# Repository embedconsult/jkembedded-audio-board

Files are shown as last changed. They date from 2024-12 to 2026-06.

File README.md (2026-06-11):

# JK-Embedded Audio Board

KiCad design files, firmware plans, and host-side utilities for the JK-Embedded Audio Board and its mikroBUS HAT companion. The design targets multiple SBC hosts (BeaglePlay, BeagleY-AI, TI AM62/68/69 SK-EVM) and uses an MSPM0L1105TRGER as a GPO-extender for configuring the analog muxes.

## Tasks

- [X] A. Requirement analysis (2 days)
- [X] B. Schematic entry (1 weeks after A approval)
- [X] C. Layout (1 weeks after B approval)
- [X] D. Prototype coordination (3 days after C approval)
- [X] E. Test code development (2 weeks after C approval)
- [X] F. Test bench materials (2 weeks after C approval)
- [X] G. Prototype delivery (3 weeks after C approval)
- [ ] H. Sign-off on production design
- [ ] I. First production units ship (12 weeks after H approval)

## Project scope
- **Hardware**: KiCad schematics/PCB for the audio board, mikroBUS HAT, and reference bring-up materials.
- **Firmware**: MSPM0 GPO-extender for mux control (Zephyr preferred; TI SDK acceptable) plus host-side programming utilities and sample integrations for Linux/Zephyr-based hosts.
- **Host integration**: Device-tree overlays and minimal driver/configuration routines for the Si5351 clock generator and the audio codec. Aim to upstream DTS fragments where possible.
- **Production/test utilities**: Board programmers and validation helpers for all target hosts except BeaglePlay (which does not use the mikroBUS HAT).

## Repository layout
- `AGENTS.md` — contribution expectations (scope, CI, documentation rules).
- `docs/` — high-level design notes, firmware/utility plans, and host integration checklists.
- `firmware/` — all firmware and host-side utilities.
  - `mspm0-gpo-extender/` — Zephyr/TI SDK project for the MSPM0L1105TRGER mux controller.
  - `host-programmers/` — Rust/Crystal utilities to program the MSPM0 over I2C/BSL from aarch64 Linux hosts.
  - `host-integration/` — device-tree overlays, clock generator configuration helpers, and sample host code.
- `ci/` — shared CI scripts (e.g., structure checks) used by GitLab and GitHub workflows.
- KiCad sources remain at the repository root for the board and HAT designs.

## Requirements

1. Compatible with RPi HAT connector
2. Texas Instruments TAC5112 for audio codec
3. Texas Instruments DAC53002 for clock generator VCXO control
4. Silicon Laboratories Si5351 clock generator with VCXO (Si5351B)
5. SBC signals:
   * AFSX (WRD) - left/right frame sync (audio board -> SBC)
   * ACLKX (BIT) - bit clock (audio board -> SBC)
   * AXR0 (DI) - data in (SBC -> audio board)
   * AXR1 (DO) - data out (audio board -> SBC)
   * EQEP_A (CNT) - clock counting (audio board -> SBC)
   * CPTSx_HWnTSPUSH or GPIO (TS) - timestamp event (audio board -> SBC)
   * SDA - I<sup>2</sup>C data I/O
   * SCL - I<sup>2</sup>C clock I/O
6. Audio signals:
   * Jacks for stereo in and out at line level (1V<sub>RMS</sub> @ 100Ω) or better
   * Additional I/Os over 3-pin headers
7. Texas Instruments MSPM0L1105TRGER for header signal mapping

## MSPM0 GPO-extender goals
- Mimic a simple I2C GPO-expander interface for host control while optionally auto-selecting mux states per detected host.
- Use BOOTLOADER_SEL and RESET signals to enter the MSPM0 ROM BSL for programming via I2C.
- Keep the binary footprint small and configuration-driven to ease host integration.

## Current validated state
- The local `zephyr` `audio-board` branch includes working MSPM0L110x GPIO support for this board.
- The shared Zephyr board definition for MSPM0 firmware now lives at `firmware/boards/arm/mikrobus_hat/`.
- The BeagleY-AI flash path is working with:
  - `GPIO24` as `MCU_RESET`
  - `GPIO25` as `MCU_BOOTLOADER_SEL`
  - `/dev/hat/mcu_i2c0` as the MSPM0 I2C/BSL bus
  - `bb-imager-cli --verbose flash zepto ... --reset-gpio GPIO24 --bsl-gpio GPIO25 /dev/hat/mcu_i2c0`
- `firmware/blinky/` is the clean minimal Zephyr GPIO validation app and is a better board/GPIO smoke test than the earlier ad hoc debug images.
- The MSPM0 now emulates a `pca9538`-compatible GPIO expander at `0x20`, and Linux can bind the standard `gpio-pca953x` driver to it.
- Zephyr GPIO control has been verified electrically on:
  - `PA19` / `PA20` at `J6`
  - `PA9` / `PA10` through the muxes using an `AN -> INT` short on the mikroBUS socket

## Fresh System Reproduction

Use this path when starting from a fresh BeagleY-AI system with:

- the mikroBUS HAT installed
- the audio board installed on the mikroBUS socket
- no validation jumpers fitted
- no MSPM0 GPIO overlay applied
- no audio overlay applied
- no 1-wire EEPROM programming assumptions

This is the current reproducible starting point for bring-up.

### What to read first

- [bringup.md](/home/beagle/jkembedded-audio-board/bringup.md)
- [firmware/mspm0-gpo-extender/README.md](/home/beagle/jkembedded-audio-board/firmware/mspm0-gpo-extender/README.md)
- [firmware/host-programmers/README.md](/home/beagle/jkembedded-audio-board/firmware/host-programmers/README.md)

### Minimum prerequisites

- `/dev/hat/mcu_i2c0` exists and resolves to the HAT-facing I2C bus
- GPIO line names `GPIO24` and `GPIO25` exist on the host
- `bb-imager-cli` is available from the checked-out `bb-imager-rs` repo
- Zephyr is checked out on the `audio-board` branch and reachable through this repo's `west.yml`

### Reproduction steps

1. Build the MSPM0 firmware in `firmware/mspm0-gpo-extender/app`.
2. Flash it with `bb-imager-cli --verbose flash zepto ... --reset-gpio GPIO24 --bsl-gpio GPIO25 /dev/hat/mcu_i2c0`.
3. Verify the raw I2C bus before doing anything with overlays:
   - the audio board devices should still be present at `0x47`, `0x50`, and `0x60`
   - the MSPM0 application should respond at `0x20`
   - `0x48` should not still be present after returning to normal boot

### Notes

- Keep the initial reproduction point overlay-free. Bind the Linux `pca9538` client or apply the BeagleY-AI overlay only after the raw flash and raw-I2C checks pass.
- If `0x20` shows up as `UU`, a previous `pca953x` binding is still active and should be removed before treating the scan as a clean baseline.
- If `0x48` remains present after flashing, the MSPM0 is still in ROM BSL and `GPIO25` / boot-state handling needs to be checked before moving on.

## Host programmer expectations
- Produce statically linked aarch64 binaries (Rust or Crystal) with no runtime dependencies beyond the Linux kernel.
- Discover GPIO line names and I2C controller symlinks when available; otherwise fall back to board-specific static mappings or CLI arguments.
- Include board profiles for BeagleY-AI, TI AM62 SK-EVM, TI AM68 SK-EVM, and TI AM69 SK-EVM; BeaglePlay is excluded from programming because it does not use the mikroBUS HAT.

## CI overview
- **GitLab CI**: Generates PDFs, BOMs, fabrication outputs, renders, and packaging assets from the KiCad sources, plus layout sanity checks. See `.gitlab-ci.yml`.
- **GitHub Actions**: Mirrors the layout checks and KiCad artifact generation for GitHub users. See `.github/workflows/ci.yml`.
- Shared CI logic lives in `ci/check-project-structure.sh`. Update both pipelines when adding new build steps.

## HAT signal mapping

Where do the various SBC signals need to go to the board connector for each board?

| SBC signal | BP-AM62 | BYAI-AM67A | SK-AM62 | SK-AM68/9 |
| --- | --- | --- | --- | --- |
| WRD | RST (D20)  | 35 (C26) | J7 | 35 |
| BIT | PWM (B20)  | 12 (D25) | 11 (B20)  | 12 |
| DI | AN (E18) | 38 (F23) | 33 (E18)  | 38 |
| DO | INT (B18)  | 40 (B25) | 36 (B18)  | 40 |
| CNT | CIPO (B19) | 36 (A25) | 38 (B19)  | 11 |
| TS | COPI (A19) | 19 (B12) | 19 (B13)  | 19 |
| SDA | SDA (B15)  | 3 (E11) | 3 (K24) | 3 |
| SCL | SCL (A15)  | 5 (B13) | 5 (K22) | 5 |
| 3.3V | +3.3V | 1,17 | 1,17 | 1,17 |
| 5.0V | +5V | 2,4 | 2,4 | 2,4 |
| GND | GND | GND | GND | GND |
| RX | RX (C15) | 10 (C27) | 10 (C15)  | 10 |
| TX | TX (E15) | 8 (F24) | 8 (E15) | 8 |
| SCK | SCK (A20)  | 23 (A9) | 23 (A14)  | 23 |
| SDQ | CS (E19) | 24 (C12) | 24 (A13)  | 24 |

The host overlays use Raspberry Pi / BeagleY-AI-style GPIO line names for the
HAT pins so that host tools can use one line-name vocabulary across boards.
The mikroBUS mux can route some signals to more than one HAT pin; each alternate
route gets its own row and uses the `_A`, `_B`, or `_C` suffix from the HAT
schematic signal names.

| HAT signal | HAT pin | Overlay line name | BeagleY-AI SoC / GPIO | SK-AM62 SoC / GPIO | SK-AM68 SoC / GPIO | SK-AM69 SoC / GPIO |
| --- | --- | --- | --- | --- | --- | --- |
| RST_WRD_A  | 7 | `GPIO4` | W26 / GPIO0_38 | J7 | G25 / WKUP_GPIO0_66 | N34 / WKUP_GPIO0_66 |
| RST_WRD_B  | 35 | `GPIO19` | C26 / GPIO1_12 | D20 / GPIO1_13 | V28 / GPIO0_47 | AD33 / GPIO0_47 |
| PWM_BIT_A  | 11 | `GPIO17` | A26 / GPIO1_8 | B20 / GPIO1_11 | U24 / GPIO0_42 | AF34 / GPIO0_42 |
| PWM_BIT_B  | 12 | `GPIO18` | D25 / GPIO1_11 | G20 / GPIO1_14 | AA24 / GPIO0_46 | AC34 / GPIO0_46 |
| AN_DI_A | 33 | `GPIO13` | E19 / GPIO1_18 | B20 / GPIO1_10 | AE27 / GPIO0_51 | AM37 / GPIO0_51 |
| AN_DI_B | 38 | `GPIO20` | F23 / GPIO1_10 | B19 / GPIO1_8 | T28 / GPIO0_48 | AD38 / GPIO0_48 |
| INT_DO_A | 36 | `GPIO16` | A25 / GPIO1_7 | B18 / GPIO1_9 | T23 / GPIO0_41 | AJ36 / GPIO0_41 |
| INT_DO_B | 40 | `GPIO21` | B25 / GPIO1_9 | C19 / GPIO1_7 | U25 / GPIO0_45 | AL34 / GPIO0_45 |
| CIPO_CNT_A | 38 | `GPIO20` | F23 / GPIO1_10 | B19 / GPIO1_8 | T28 / GPIO0_48 | AD38 / GPIO0_48 |
| CIPO_CNT_B | 36 | `GPIO16` | A25 / GPIO1_7 | B18 / GPIO1_9 | T23 / GPIO0_41 | AJ36 / GPIO0_41 |
| CIPO_CNT_C | 11 | `GPIO17` | A26 / GPIO1_8 | B20 / GPIO1_11 | U24 / GPIO0_42 | AF34 / GPIO0_42 |
| COPI_TS | 19 | `GPIO10` | B12 / MCU_GPIO0_3 | B13 / GPIO1_18 | E24 / WKUP_GPIO0_1 | J34 / WKUP_GPIO0_1 |
| SDA | 3 | `GPIO2` | E11 / MCU_GPIO0_18 | K24 / GPIO0_44 | AF28 / GPIO0_4 | G34 / WKUP_GPIO0_87 |
| SCL | 5 | `GPIO3` | B13 / MCU_GPIO0_17 | K22 / GPIO0_43 | AD25 / GPIO0_5 | M35 / WKUP_GPIO0_65 |
| RX | 10 | `GPIO15` | C27 / GPIO1_13 | C15 / UART5_RXD | AC24 / GPIO0_2 | AJ33 / GPIO0_2 |
| TX | 8 | `GPIO14` | F24 / GPIO1_14 | E15 / UART5_TXD | W25 / GPIO0_1 | AG36 / GPIO0_1 |
| SCK | 23 | `GPIO11` | A9 / MCU_GPIO0_2 | A14 / GPIO1_17 | D26 / WKUP_GPIO0_0 | H38 / WKUP_GPIO0_0 |
| CS_SDQ | 24 | `GPIO8` | C12 / MCU_GPIO0_0 | A13 / GPIO1_15 | C27 / WKUP_GPIO0_3 | J36 / WKUP_GPIO0_3 |
| MCU_RESET  | 18 | `GPIO24` | C8 / MCU_GPIO0_10 | K25 / GPIO0_39 | AD24 / GPIO0_13 | AJ34 / GPIO0_13 |
| MCU_BOOTLOADER_SEL | 22 | `GPIO25` | P21 / GPIO0_42 | A13 / GPIO0_14 | J27 / WKUP_GPIO0_67 | M34 / WKUP_GPIO0_67 |

## GPIO switches

The MSPM0 firmware exposes these selector lines through the emulated
`pca9538` GPIO expander:

| PCA9538 bit | Selector line | MSPM0 pin | SBC signal | HAT pin routes |
| --- | --- | --- | --- | --- |
| 0 | `RST_SEL` | `PA3` | `WRD` | `35` or `7` / `J7` |
| 1 | `PWM_SEL` | `PA4` | `BIT` | `11` or `12` |
| 2 | `AN_SEL` | `PA9` | `DI` | `33` or `38` |
| 3 | `INT_SEL` | `PA10` | `DO` | `36` or `40` |
| 4 | `CIPO_SEL_0`  | `PA11` | `CNT` | `38`, `36` or `11` |
| 5 | `CIPO_SEL_1`  | `PA15` | `CNT` | `38`, `36` or `11` |

Single-bit selector settings:

| Selector line | `0` | `1` |
| --- | --- | --- |
| `RST_SEL` | `WRD` on HAT pin `7` (`GPIO4`) / `J7` | `WRD` on HAT pin `35` (`GPIO19`) |
| `PWM_SEL` | `BIT` on HAT pin `11` (`GPIO17`) | `BIT` on HAT pin `12` (`GPIO18`) |
| `AN_SEL` | `DI` on HAT pin `33` (`GPIO13`)  | `DI` on HAT pin `38` (`GPIO20`)  |
| `INT_SEL` | `DO` on HAT pin `36` (`GPIO16`)  | `DO` on HAT pin `40` (`GPIO21`)  |

Two-bit `CNT` / `CIPO` selector settings:

| `CIPO_SEL_0` | `CIPO_SEL_1` | `CNT` on |
| --- | --- | --- |
| `0` | `0` | not connected |
| `0` | `1` | HAT pin `38` (`GPIO20`) |
| `1` | `0` | HAT pin `36` (`GPIO16`) |
| `1` | `1` | HAT pin `11` (`GPIO17`) |

Selector settings for each target host:

| Target host  | `RST_SEL` | `PWM_SEL` | `AN_SEL` | `INT_SEL` | `CIPO_SEL_0` | `CIPO_SEL_1` |
| --- | --- | --- | --- | --- | --- | --- |
| `BYAI-AM67A` | `1` | `1` | `1` | `1` | `1` | `0` |
| `SK-AM62` | `0` | `0` | `0` | `0` | `0` | `1` |
| `SK-AM68/9`  | `1` | `1` | `1` | `1` | `1` | `1` |

Use `firmware/host-integration/linux/set-mux-profile.sh --host <profile>` to
apply these selector settings from Linux once the MSPM0 `pca9538` target is
reachable. Supported profile names include `byai-am67a`, `sk-am62`, `sk-am68`,
and `sk-am69`; see `firmware/host-integration/README.md` for options and
examples. The base HAT overlays under `firmware/host-integration/linux/<host>/`
provide line names and input pinmux defaults without applying any add-on-board
selector profile.

## Next steps
- Decide whether to keep the measured selector polarity as-is in production firmware or to invert any lines in software before exposing host profiles.
- Decide the production MSPM0 firmware interface:
  - fixed per-host mux profiles, or
  - an I2C target / GPO-expander compatible interface.
- Keep `firmware/blinky/` as the basic board/GPIO validation sample.
- Add device-tree overlays and minimal driver hooks in `firmware/host-integration/` for clock generator initialization and codec wiring.
- Integrate firmware and utility builds into both CI systems.

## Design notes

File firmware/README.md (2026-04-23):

# Firmware and Utilities

This directory contains all firmware and host-side utilities for the JK-Embedded Audio Board and mikroBUS HAT.

## Contents
- `boards/`: Shared Zephyr board definitions for MSPM0 firmware apps. `boards/arm/mikrobus_hat/` is the single source of truth for the MSPM0L1105 HAT controller board.
- `blinky/`: Minimal Zephyr GPIO validation app used to prove board support and flashing on the MSPM0L1105.
- `mspm0-gpo-extender/`: Firmware for the MSPM0L1105TRGER mux controller. Zephyr is preferred; TI SDK is acceptable if Zephyr is blocked.
- `host-programmers/`: Rust/Crystal programmer utilities for aarch64 Linux hosts to load the mux-control firmware over I2C using the MSPM0 ROM BSL.
- `host-integration/`: Device-tree overlays, configuration helpers, and example host code (Linux/Zephyr) for the clock generator and audio codec.

## Guidelines
- Keep host utilities self-contained with static linking; avoid Python or PyPI dependencies.
- Update CI workflows when adding build targets or tests for these components.
- Document board-specific GPIO and I2C mappings alongside the corresponding code.

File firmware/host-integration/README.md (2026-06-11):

# Host Integration Assets

Device-tree overlays, configuration helpers, and example code for integrating the audio board and mikroBUS HAT with supported hosts.

## Focus areas
- Si5351 clock generator setup with DAC53002 VCXO control.
- Audio codec wiring and driver bindings using mainline-compatible DTS fragments.
- Mux control defaults coordinated with the MSPM0 GPO-extender firmware.

## Deliverables
- DTS overlays per supported host (BeagleY-AI, TI AM62/68/69 SK-EVM).
- Minimal configuration utilities or scripts to apply overlays and initialize clocks.
- Notes on upstreaming overlays/driver tweaks to mainline Linux/Zephyr.

## Current MSPM0 host integration

The MSPM0 now emulates a `pca9538`-compatible GPIO expander at `0x20` on the
host-visible I2C bus `/dev/hat/mcu_i2c0` (`i2c-1` on the current BeagleY-AI
setup).

Do not start here for fresh-system bring-up. The initial reproduction point is
the raw build/flash/raw-I2C flow in `bringup.md`, before any overlay or manual
Linux `pca953x` binding is introduced.

### Host-board overlays

Use the matching `jkembedded-mikrobus-hat.dts` overlay under
`firmware/host-integration/linux/<host>/` to instantiate the Linux
`gpio-pca953x` driver with stable line names and base HAT GPIO line names.

Available overlays:

| Host board | Overlay | I2C target |
| --- | --- | --- |
| BeagleY-AI / AM67A | `linux/beagley-ai/jkembedded-mikrobus-hat.dts` | observed live path `/bus@f0000/bus@4000000/i2c@4900000` |
| TI AM62 SK-EVM | `linux/sk-am62/jkembedded-mikrobus-hat.dts` | `&main_i2c2` |
| TI AM68 SK-EVM | `linux/sk-am68/jkembedded-mikrobus-hat.dts` | `&main_i2c4` |
| TI AM69 SK-EVM | `linux/sk-am69/jkembedded-mikrobus-hat.dts` | `&mcu_i2c0` |

Each overlay exposes these selector lines:

- `RST_SEL`
- `PWM_SEL`
- `AN_SEL`
- `INT_SEL`
- `CIPO_SEL_0`
- `CIPO_SEL_1`

These base HAT overlays name the MSPM0 selector lines and host-side HAT GPIO
lines, but they do not drive selector GPIOs to any target profile. Apply a
separate mikroBUS add-on-board overlay, or use the helper below, when a board
needs specific mux settings. The BeagleY-AI overlay keeps the existing live
`i2c-1` `target-path` because that path was validated on hardware. The SK-EVM
overlays use upstream board labels so they follow the base DTS I2C bus layout
used by each target kernel.

### Host mux profile helper

Use `firmware/host-integration/linux/set-mux-profile.sh` after the MSPM0
`pca9538` target is reachable to drive all six selector lines for a supported
host-board profile in one command. The helper uses the overlay-provided line
names when available and otherwise falls back to the detected `pca9538`
`gpiochip` offsets. It binds a temporary Linux `pca9538` client at `0x20`
on `i2c-1` by default when no client exists yet. The base HAT overlays do not
hog the selector GPIOs, so the helper can be used after the overlay loads when
you need to change
profiles interactively.

```console
./firmware/host-integration/linux/set-mux-profile.sh --host byai-am67a
./firmware/host-integration/linux/set-mux-profile.sh --host sk-am62
./firmware/host-integration/linux/set-mux-profile.sh --host sk-am68
./firmware/host-integration/linux/set-mux-profile.sh --host sk-am69
```

Pass `--i2c-bus <bus>` or set `I2C_BUS=<bus>` when the MSPM0 target is on a
different Linux I2C adapter. Use `--dry-run` to print the selected values
without touching GPIOs.

### Validation recipe

Current proven setup:

1. Remove the audio board.
2. Short mikroBUS `AN` to `INT`.
3. Bind the `pca9538` client either by overlay at boot or temporarily with:

```console
echo pca9538 0x20 | sudo tee /sys/bus/i2c/devices/i2c-1/new_device
```

4. Run the scripted validator:

```console
./firmware/host-integration/linux/beagley-ai/validate-mux.sh sample an-int
```

Manual hold-and-probe mode is available too:

```console
./firmware/host-integration/linux/beagley-ai/validate-mux.sh hold an-int low
./firmware/host-integration/linux/beagley-ai/validate-mux.sh hold an-int high
```

The script uses the named selector lines when the overlay is active and falls
back to `gpiochip3` offsets otherwise.

### Remaining selector setups

Use these jumper configurations to finish validating the remaining mux controls:

- `AN -> PWM`

```console
./firmware/host-integration/linux/beagley-ai/validate-mux.sh sample an-pwm
```

Expected output on the current validated board:

```console
AN->PWM low state (expect GPIO18=1 GPIO17=0): 1 0
AN->PWM high state (expect GPIO18=0 GPIO17=1): 0 1
```

- `AN -> MISO`

```console
./firmware/host-integration/linux/beagley-ai/validate-mux.sh sample an-miso
```

Expected output on the current validated board:

```console
AN->MISO state 0 (CIPO_SEL_0=0 CIPO_SEL_1=0) -> GPIO16 GPIO20 GPIO17: 1 1 1
AN->MISO state 1 (CIPO_SEL_0=0 CIPO_SEL_1=1) -> GPIO16 GPIO20 GPIO17: 1 0 1
AN->MISO state 2 (CIPO_SEL_0=1 CIPO_SEL_1=0) -> GPIO16 GPIO20 GPIO17: 0 1 1
AN->MISO state 3 (CIPO_SEL_0=1 CIPO_SEL_1=1) -> GPIO16 GPIO20 GPIO17: 1 1 0
```

- `AN -> RST`

```console
./firmware/host-integration/linux/beagley-ai/validate-mux.sh sample an-rst
```

Probe or read HAT pin `35` (`GPIO19`) and HAT pin `7` (`GPIO4`). HAT pin `7`
is tied to the same signal that is also brought out at `J7` through `R23`
(`0 ohm`), so it is the preferred validation point on this PCB revision.

Expected output:

```console
AN->RST low state (expect GPIO19=1 GPIO4=0): 1 0
AN->RST high state (expect GPIO19=0 GPIO4=1): 0 1
```

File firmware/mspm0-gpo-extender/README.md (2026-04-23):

# MSPM0 GPO-Extender Firmware

The MSPM0L1105TRGER manages mux control for the audio board and mikroBUS HAT.

## Objectives
- Expose mux selection over I2C with a GPO-expander-like register map.
- Provide optional host-detection logic to choose defaults based on SBC profiles.
- Keep the firmware small and configuration-driven; Zephyr preferred, TI SDK acceptable.

## Current state

- The shared Zephyr board `mikrobus_hat` is building and flashing successfully.
- The current reproducible bring-up point is intentionally overlay-free:
  - mikroBUS HAT installed
  - audio board installed
  - no validation jumpers
  - no MSPM0 GPIO overlay applied yet
- Basic GPIO validation is working:
  - `firmware/blinky/` is the clean minimal board support / GPIO smoke test.
  - The `app/` image has been used to verify `PA19` / `PA20` at `J6`.
  - The `app/` image has also been used to verify `PA9` / `PA10` through the muxes with a host-side loopback test.
- PCA9538-style I2C target validation is working:
  - The current `app/` image emulates a `pca9538`-compatible target at `0x20`.
  - Direct `i2ctransfer` register reads/writes succeed.
  - A standard Linux `gpio-pca953x` client can bind at `0x20`.
  - With the `AN -> INT` loopback in place, Linux-driven expander bits 2 and 3 select the expected mux route.
- The BeagleY-AI flash path is now:

```sh
REPO_ROOT="$(git rev-parse --show-toplevel)"
BB_IMAGER_CLI="${BB_IMAGER_CLI:-../bb-imager-rs/target/debug/bb-imager-cli}"
"${BB_IMAGER_CLI}" --verbose flash zepto \
  "${REPO_ROOT}/build/mspm0-zephyr/zephyr/zephyr.hex" \
  --reset-gpio GPIO24 \
  --bsl-gpio GPIO25 \
  /dev/hat/mcu_i2c0
```

- The current `app/` is still a validation app, not the final production mux-control firmware.

## Expected inputs/outputs
- **Inputs**: I2C commands from the host; BOOTLOADER_SEL and RESET to enter MSPM0 BSL.
- **Outputs**: Deterministic mux control lines for each supported host profile.

## Remaining work
- Document and preserve the clean raw-I2C bring-up path before enabling overlays
- Decide how host-profile policy should sit on top of the PCA9538 register model
- Add any host integration needed for line naming or board-specific defaults when binding the Linux `pca953x` client

## Zephyr board configuration

- **Board identifier**: `mikrobus_hat` (see `firmware/boards/arm/mikrobus_hat/`).
- **I2C role**: target/peripheral on `PA0`/`PA1`, currently emulating an 8-bit `pca9538` GPIO expander at `0x20` so existing Linux `pca953x` drivers can toggle the mux selects without changes.
- **I2C pins**: `PA0` = SDA (`HAT_SDA`), `PA1` = SCL (`HAT_SCL`).
- **Bootloader pins**: `PA18` = `MCU_BOOTLOADER_SEL`, `NRST` exposed via the reset net shared with the programming header.
- **Mux GPIO assignments (PCA9538 bit order)**:
  0. `PA3` → `RST_WRD_SEL`
  1. `PA4` → `PWM_BIT_SEL`
  2. `PA9` → `AN_DI_SEL`
  3. `PA10` → `INT_DO_SEL`
  4. `PA11` → `CIPO_CNT_SEL0`
  5. `PA15` → `CIPO_CNT_SEL1`
  6. reserved for future use
  7. reserved for future use

The shared board DTS in `firmware/boards/arm/mikrobus_hat/mikrobus_hat.dts` documents the current pinctrl and validation GPIO map. The current `app/` implementation uses the PCA9538 register model directly rather than the older EEPROM target shim.

## Build and CI smoke test

The Zephyr build smoke test lives in `app/` and targets `mikrobus_hat`. The repo `west.yml` now points Zephyr at the `audio-board` branch and imports only the required modules (`cmsis_6` and `hal_ti`). Run the same script locally from the repo root:

```sh
./ci/build-zephyr-mspm0.sh
```

The script initializes an isolated west workspace under `build/`, uses the Zephyr SDK toolchain if it is installed at `/opt/zephyr-sdk` (as in CI containers), and rebuilds from a clean tree to catch board or configuration regressions. Local bring-up also works with any sibling or external Zephyr checkout on the same branch. You can perform the same steps manually:

```sh
west init -l .
west update --narrow --fetch-opt=--depth=1
west build -p always \
  -b mikrobus_hat \
  "$PWD/firmware/mspm0-gpo-extender/app" \
  --build-dir "$PWD/build/mspm0-zephyr" \
  -- \
  -DBOARD_ROOT="$PWD/firmware"
```

CI also runs `clang-format` (using `.clang-format` from Zephyr) and `dtslint.py` on the board DTS before building.

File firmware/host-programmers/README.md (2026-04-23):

# Host Programmer Utilities

Utilities in this directory program the MSPM0L1105TRGER mux-control firmware from supported hosts.

## Requirements
- Rust or Crystal implementation only; produce statically linked aarch64 Linux binaries.
- No Python or PyPI dependencies.
- Use GPIO line names and I2C controller symlinks when available; allow CLI overrides and static board profiles otherwise.

## Target hosts
- BeagleY-AI
- TI AM62 SK-EVM
- TI AM68 SK-EVM
- TI AM69 SK-EVM

BeaglePlay is excluded because it does not use the mikroBUS HAT.

## Current status
- GPIO line-name based BSL entry is working on the BeagleY-AI host
- `bb-imager-cli flash zepto` is the current working flash path
- The working invocation is:

```console
BB_IMAGER_CLI="${BB_IMAGER_CLI:-../bb-imager-rs/target/debug/bb-imager-cli}"
"${BB_IMAGER_CLI}" --verbose flash zepto \
  /path/to/zephyr.hex \
  --reset-gpio GPIO24 \
  --bsl-gpio GPIO25 \
  /dev/hat/mcu_i2c0
```

- Flash verify may still false-fail on this transport; use `--no-verify` if the
  image is written successfully but the CRC stage reports an error

## Planned features
- Board detection and safe default mux selection
- More robust verification/readback over I2C BSL
- Optional dry-run mode for validation during production testing

## BeagleY-AI (current target) resource mapping

### Image used for testing

```
$ cat /etc/dogtag
BeagleBoard.org Debian Bookworm Xfce Image 2025-11-25
```

### HAT I2C

Preferred path:

`/dev/hat/mcu_i2c0`

Resolved bus on this host:

`/dev/i2c-1`

```
beagle@beagle:~/jkembedded-audio-board$ i2cdetect -y -r 1
     0  1  2  3  4  5  6  7  8  9  a  b  c  d  e  f
00:                         -- -- -- -- -- -- -- -- 
10: -- -- -- -- -- -- -- -- -- -- -- -- -- -- -- -- 
20: -- -- -- -- -- -- -- -- -- -- -- -- -- -- -- -- 
30: -- -- -- -- -- -- -- -- -- -- -- -- -- -- -- -- 
40: -- -- -- -- -- -- -- 47 48 -- -- -- -- -- -- -- 
50: 50 -- -- -- -- -- -- -- -- -- -- -- -- -- -- -- 
60: 60 -- -- -- -- -- -- -- -- -- -- -- -- -- -- -- 
70: -- -- -- -- -- -- -- --                         
```

### HAT GPIO

| Signal | pin | linename |
| --- | --- | --- |
| MCU_RESET | 18  | GPIO24 |
| MCU_BOOTLOADER_SEL | 22  | GPIO25 |

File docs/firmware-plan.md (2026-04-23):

# Firmware and Host Integration Plan

This document outlines the planned firmware, host utilities, and integration steps for the JK-Embedded Audio Board and mikroBUS HAT.

## MSPM0L1105TRGER GPO-extender
- **Goal**: Provide a simple I2C-accessible GPIO expander interface, or a fixed mux-profile image, to select mux configurations for each supported host platform.
- **Preferred stack**: Zephyr. This is no longer blocked: local board support, flashing, and GPIO control are working.
- **Bootloading**: The current working path uses `bb-imager-cli flash zepto` with line names `GPIO24` and `GPIO25` and the host bus `/dev/hat/mcu_i2c0`.
- **Host awareness**: Support optional host detection (GPIO line names or static profiles) to pre-select safe mux defaults.
- **Validated so far**:
  - `PA19` / `PA20` GPIO control at `J6`
  - `AN_SEL` / `INT_SEL` mux control via `AN -> INT` loopback
  - `PWM_SEL` mux control via `AN -> PWM` loopback
  - `CIPO_SEL_0` / `CIPO_SEL_1` mux control via `AN -> MISO` loopback
  - `RST_SEL` polarity using HAT pin `7` (`GPIO4`), which is tied to the `J7` signal through `R23` (`0 ohm`)
  - PCA9538-compatible I2C target emulation at `0x20`
  - Linux `gpio-pca953x` binding against the emulated target

## Host programmer utility
- **Language**: Rust or Crystal only; produce statically linked aarch64 binaries with no dynamic library dependencies.
- **Functionality**:
  - Detect the appropriate I2C controller via `/dev` symlinks when present; otherwise select per-board defaults.
  - Assert BOOTLOADER_SEL/RESET to enter the BSL and program the MSPM0 with the mux-control firmware image.
  - Offer command-line arguments to override board detection, I2C bus number, and GPIO line names.
- **Current working command**:

```sh
BB_IMAGER_CLI="${BB_IMAGER_CLI:-../bb-imager-rs/target/debug/bb-imager-cli}"
"${BB_IMAGER_CLI}" --verbose flash zepto \
  /path/to/zephyr.hex \
  --reset-gpio GPIO24 \
  --bsl-gpio GPIO25 \
  /dev/hat/mcu_i2c0
```
- **Targets**: BeagleY-AI, TI AM62 SK-EVM, TI AM68 SK-EVM, TI AM69 SK-EVM. BeaglePlay is not programmed because it does not use the mikroBUS HAT.

## Linux/Zephyr host integration
- **Clock generator (Si5351)**: Provide device-tree overlays and minimal configuration helpers to initialize VCXO control via DAC53002.
- **Audio codec**: Rely on mainline support for the TI AIC/TAS codec; supply DTS fragments to bind to the correct buses and clocks.
- **Configuration flow**: host binds PCA9538-compatible MSPM0 target -> mux selection via named GPIO lines -> clock generator setup -> codec registration.
- **Upstreaming**: Keep DTS overlays minimal and align node names/compatible strings with mainline conventions to ease upstream submission.

## Directory pointers
- `firmware/mspm0-gpo-extender/`: Firmware sources, build scripts, board configuration overlays, and usage documentation.
- `firmware/host-programmers/`: Programmer utility, board profiles, release binaries, and usage documentation.
- `firmware/host-integration/`: DTS overlays, helper scripts, and documentation for host configuration.
- `docs/`: Additional design notes, bring-up procedures, and any shared usage documentation.

## Next integration steps
1. Update host-side integration and default-profile code to use the measured `RST_SEL` polarity: `0 -> HAT pin 7 / GPIO4 / J7`, `1 -> HAT pin 35 / GPIO19`.
2. Apply the BeagleY-AI host overlay in normal boot flows so Linux exposes the emulated PCA9538 lines as `RST_SEL`, `PWM_SEL`, `CIPO_SEL_0`, `CIPO_SEL_1`, `AN_SEL`, and `INT_SEL` without manual `new_device` binding.
3. Decide the production MSPM0 firmware policy on top of the validated PCA9538 register model: pure host-controlled muxing, fixed power-on defaults, or host-profile-based defaults.

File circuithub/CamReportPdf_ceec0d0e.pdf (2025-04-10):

Single PCB View - Original

Top View | Bottom View

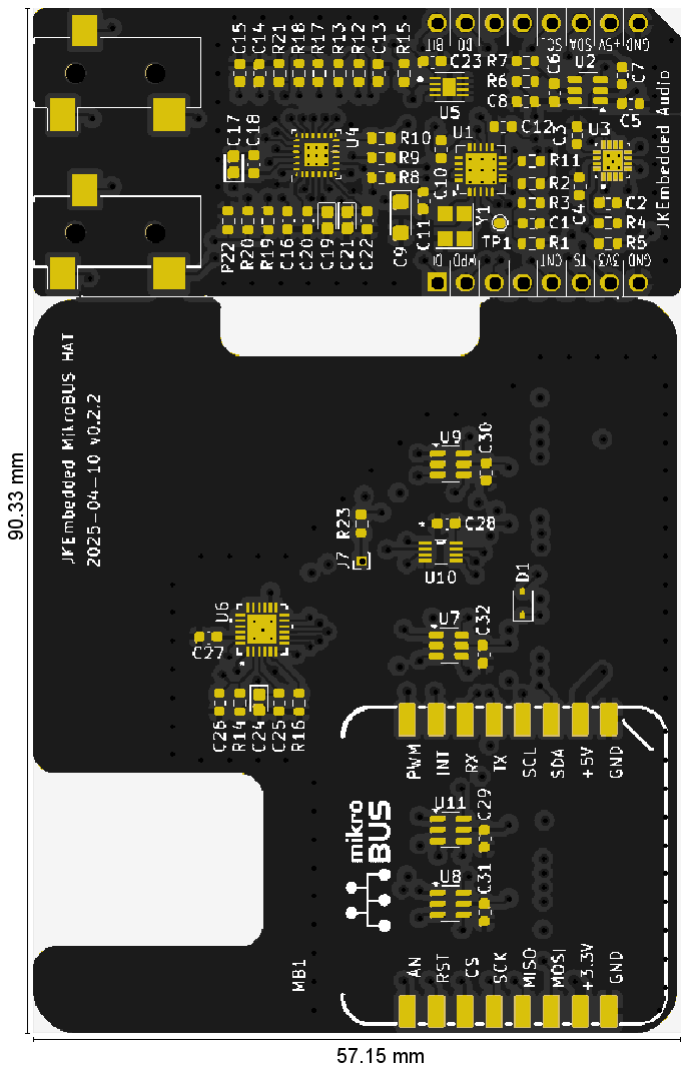
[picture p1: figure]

Summary - General - Original

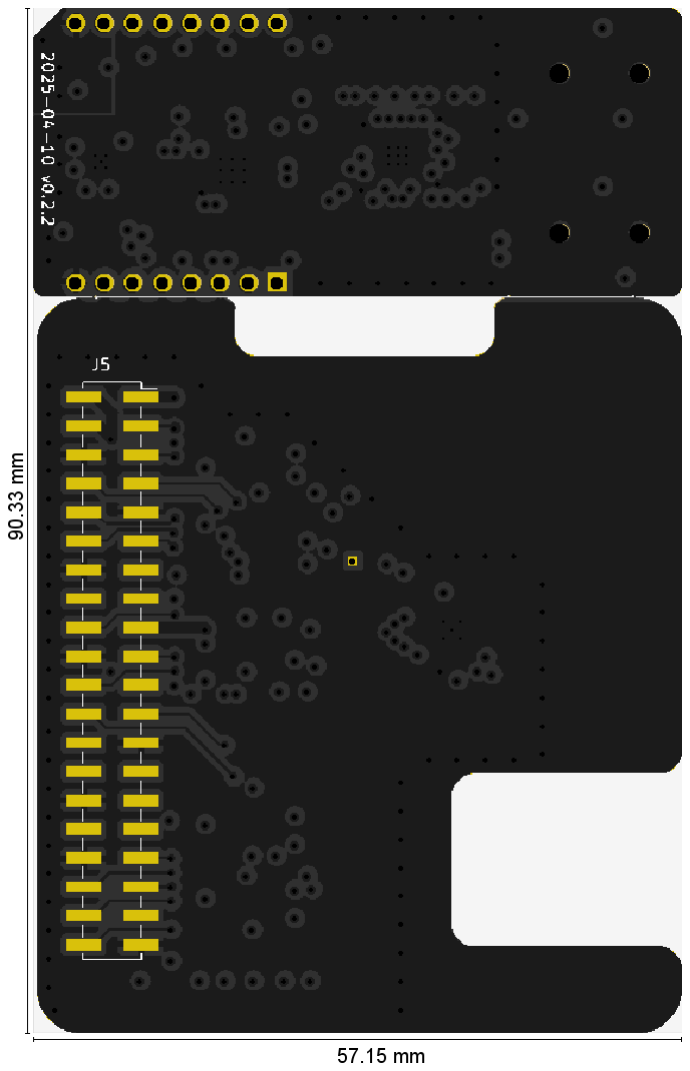
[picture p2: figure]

PCB Size | 57.15 mm x 90.329 mm | Customer Panel Size
PCB Thickness | 1.6 mm | Max. Aspect Ratio on PTH | 6.4
Copper Layers | 4 | Pressing Stages | 1
Surface Finish | unknown | Drill Hole Density | 650 Holes/dm²
Solder Mask | Both | Testable Points | 379
Solder Mask Color | Green | Min. SMD/BGA Size | 0.24 mm
Legend | Both | !HolesInPadPth! | Yes
Legend Color | White | !HolesInPadBlind! | No
Edge Connector Area | 0 dm² | Stacked Vias
Peeloff Mask | No | Castellated | No
Carbon Mask | No | Anomalies | Yes
1 | 2 | 3 | 4 | 5 | 6 | 7 | 8 | 9
10 | 11 | 12 | 13 | 14 | 15 | 16 | 17 | 18

Summary - Copper Layer Minima - Original

Type | Copper Width | Critical Copper Width

Trace Width Critical Trace

| | | | Width | Copper to Copper Clr. | Trace to Trace Clr. | Same Net Clr. | Ring | Copper to Outline Clr.
| mm | mm | mm | mm | mm | mm | mm | mm | mm
Outer | 0.160 | 0.237 | 0.250 | 0.250 | 0.142 | 0.200 | 0.025 | 0.138 | 0.000
Inner | 0.249 | 0.250 | 0.250 | 0.250 | 0.200 | 0.200 | 0.134 | 0.125 | 0.000
Integr8tor v2023.12-240208 | Page1

The information on this document is not only based on files in a clearly defined format, but also on freely structured files and inference rules. CircuitHub strives to make it as accurate as possible, but it cannot guarantee the result in all situations. This information is used at the sole risk of its user.

Name | rev_64925.zip | Id. | 26740 - QED Handled
Report Generated on | Apr 10, 2025, 4:57:55 PM | Customer
Board Id | | Article Id

19 | 20 | 21 | 22 | 23 | | 24
25 | 26 | 27 | 28 | 29 | 30 | 31

Summary - Copper Layer Minima - Original

Type | Copper to Plated Clr. | Copper to NPTH Clr.
!Min.Clr.Overal
l!

!Min.Clr.toPad! !Min.Clr.toTrac e!

!Min.Clr.toRegi
on!

!Min.Clr.Overal
l!

!Min.Clr.toPad! !Min.Clr.toTrac e!

!Min.Clr.toRegi
on!
mm | mm | mm | mm | mm | mm | mm | mm
Outer | 0.400 | 0.400 | 0.400 | 0.676 | 0.128 | >1.600 | >1.600 | 0.128
Inner | 0.332 | 0.400 | 0.332 | 0.676 | 0.128 | >1.600 | 0.275 | 0.128

Summary - Sequences - Original

Type | Sequences | Tools | Min. End
Dia.

Max. End
Dia.
Holes | Routs | Ring on
Outer

Ring on
Inner

Hole to
Copper Clr.
| | | mm | mm | | | mm | mm | mm
PTH | 1 | 4 | 0.250 | 1.000 | 301 | 0 | 0.138 | 0.125 | 0.332
NPTH | 1 | 1 | 1.700 | 1.700 | 4 | 0 | >0.800 | >0.800 | 0.128
Total | 2 | 5 | 0.250 | 1.700 | 305 | 0 | 0.138 | 0.125 | 0.128

Summary - Rout - Original

Type | Tools | Min. End Dia. | Max. End Dia. | Rout Length
| | | | | mm | | mm | | mm
Plated
NPTH

Total

Report Generated on | Apr 10, 2025, 4:57:55 PM | Customer
Board Id | | Article Id

Stackup - Original

Pressing Stages | 1

Files - Original

Initial | Renamed | Function | Position | Color | Thickness
Base | Finished
| | | | | mm | mm
doc-top.pho | drawing_1 | drawing | top
stencil-top.pho | paste-top | paste | top
silkscreen-top.pho | silk-top | silk | top | white | unknown | unknown
solder-mask-top.pho | mask-top | mask | top | black | unknown | unknown
copper-top.pho | top | outer | 1 | | | 0.035 | unknown
copper-inner-1.pho | in2 | inner | 2 | | | 0.035 | unknown
copper-inner-2.pho | in3 | inner | 3 | | | 0.035 | unknown
copper-bottom.pho | bot | outer | 4 | | | 0.035 | unknown
solder-mask-bottom.pho | mask-bot | mask | bottom | black | unknown | unknown
silkscreen-bottom.pho | silk-bot | silk | bottom | white | unknown | unknown
stencil-bottom.pho | paste-bot | paste | bottom
drill-npth.pho | npth | unplated | 1-4
drill.pho | pth | plated | 1-4
doc-bottom.pho | drawing | drawing | bottom
outline.pho | outline | cad_outline | none

PCB (Single) - Original

PCB Size | Outline Type | Outline Length | Outline Area | Copper Layers | PCB Thickness
mm x mm | | mm | dm² | | mm
57.150 x 90.329 | real | 443.948 | 0.4695 | 4 | 1.600

Customer Panel (Delivery Array, Assembly Panel) - Original

Original Image | Panel Size | Left | Right | Top | Bottom | X Spacing | Y Spacing | PCB's | Depanel Rout Length
| mm x mm | mm | mm | mm | mm | mm | mm | | mm
Report Generated on | Apr 10, 2025, 4:57:55 PM | Customer
Board Id | | Article Id

Thickness - Original

No license to generate this information.

Copper Layer Minima & Area - Original

File | Pos. Copper Width | Critical
Copper Width

Trace Width Critical Trace Width

Copper to
Copper Clr.

Same Net
Clr.

Copper Area

mm | mm | mm | mm | mm | mm | dm² | %
top | 1 | 0.237 | 0.237 | 0.250 | 0.250 | 0.142 | 0.025 | 0.3837 | 82
in2 | 2 | 0.250 | 0.250 | 0.250 | 0.250 | 0.200 | 0.207 | 0.3817 | 81
in3 | 3 | 0.249 | 0.250 | 0.250 | 0.250 | 0.200 | 0.134 | 0.3863 | 82
bot | 4 | 0.160 | 0.250 | 0.250 | 0.250 | 0.200 | 0.134 | 0.4074 | 87

Copper Layer Minima - Copper to Drill Minima - Original

File | Pos. | Ring | Copper to Drill Clr. | Copper to Outline Clr.
Overall | Via | Laser Via Comp. | Mech. | Plated | NPTH | Overall | to Pad | to Trace | to Region
mm | mm | mm | mm | mm | mm | mm | mm | mm | mm | mm
top | 1 | 0.138 | 0.138 | 0.175 | 0.400 | 0.128 | 0.000 | 0.371 | >1.600 | 0.000
in2 | 2 | 0.125 | 0.125 | 0.175 | 0.332 | 0.128 | 0.000 | 0.371 | >1.600 | 0.000
in3 | 3 | 0.125 | 0.125 | 0.175 | 0.386 | 0.128 | 0.000 | 0.371 | >1.600 | 0.000
bot | 4 | 0.175 | 0.200 | 0.175 | 0.400 | 0.128 | 0.000 | 0.371 | >1.600 | 0.000

Copper Layers - Copper to Copper Clearances - Original

File | Pos. | Copper to Copper Clr.
Overall | Pad to Pad | Pad to Track | Track to Track | Trace to Trace
mm | mm | mm | mm | mm
top | 1 | 0.142 | 0.142 | 0.200 | 0.200 | 0.200
in2 | 2 | 0.200 | 0.200 | 0.200 | 0.200 | 0.200
in3 | 3 | 0.200 | 0.200 | 0.200 | 0.200 | 0.200
bot | 4 | 0.200 | 0.200 | 0.260 | 0.250 | 0.250

Copper Areas - Original

Side | Total | Free of | Edge Connectors
Solder Mask
(as supplied)

Solder Mask
(open vias)
Gold Mask Silver Mask | Fingers | Finger Size | Total Area

dm²

dm²

dm²

dm²

dm² | mm x mm | dm²
Top (incl. 1/2 plated holes and routs) | 0.4108 | 0.0321 | 0.0616
Bottom (incl. 1/2 plated holes and routs) | 0.4346 | 0.0185 | 0.0482
Total (incl. plated holes and routs) | 0.8453 | 0.0505 | 0.1098 | 0
Plated holes and routs | 0.0633 | 0.0083 | 0.0633
Top (without plated holes and routs) | 0.3791 | 0.0279 | 0.0300
Bottom (without plated holes and routs) | 0.4029 | 0.0143 | 0.0165
Total (without plated holes and routs) | 0.7821 | 0.0422 | 0.0465
Report Generated on | Apr 10, 2025, 4:57:55 PM | Customer
Board Id | | Article Id

Drill Tools - Original

File | Tool
Nr.
Span | Type | Function Method Filled Via | Counter | Dia. | Tol. - | Tol. + Holes
in PCB

Routs
in PCB

Double
Hits

Predrill
Hits
| | | | | | | mm | mm | mm
npth | 10 | 1-4 NPTH | mech. | mech. | unknown unknown | 1.700 0.000 0.000 | 4 | 0 | 0 | 0
pth | 10 | 1-4 PTH | via | mech. | unknown unknown | 0.250 0.000 0.000 | 28 | 0 | 0 | 0
pth | 11 | 1-4 PTH | via | mech. | unknown unknown | 0.400 0.000 0.000 | 256 | 0 | 0 | 0
pth | 12 | 1-4 PTH | comp. | mech. | unknown unknown | 0.500 0.000 0.000 | 1 | 0 | 0 | 0
pth | 13 | 1-4 PTH | comp. | mech. | unknown unknown | 1.000 0.000 0.000 | 16 | 0 | 0 | 0

Drill Tools - Drill vs Copper - Original

File | Tool
| Nr.
Span | Type | Function Method | Dia. Ring on
| | | | | | Outer | Ring on Inner | Min. Pad Size | Via in
Pad

Plated to Copper Clr.
| | | | | | | | | | !Min.Clr .Overall ! | !Min.Clr .toPad! | !Min.Clr .toTrac e! | !Min.Clr .toRegi on!
| | | | | mm | mm | mm | mm | | mm | mm | mm | mm
npth | 10 | 1-4 NPTH | mech. | mech. | 1.700 >0.800 >0.800
pth | 10 | 1-4 PTH | via | mech. | 0.250 | 0.138 | 0.125 | 0.500 | 5 | 0.332 | 0.425 | 0.332 | >0.800
pth | 11 | 1-4 PTH | via | mech. | 0.400 | 0.200 | 0.200 | 0.800 | 0 | 0.400 | 0.400 | 0.400 | 0.700

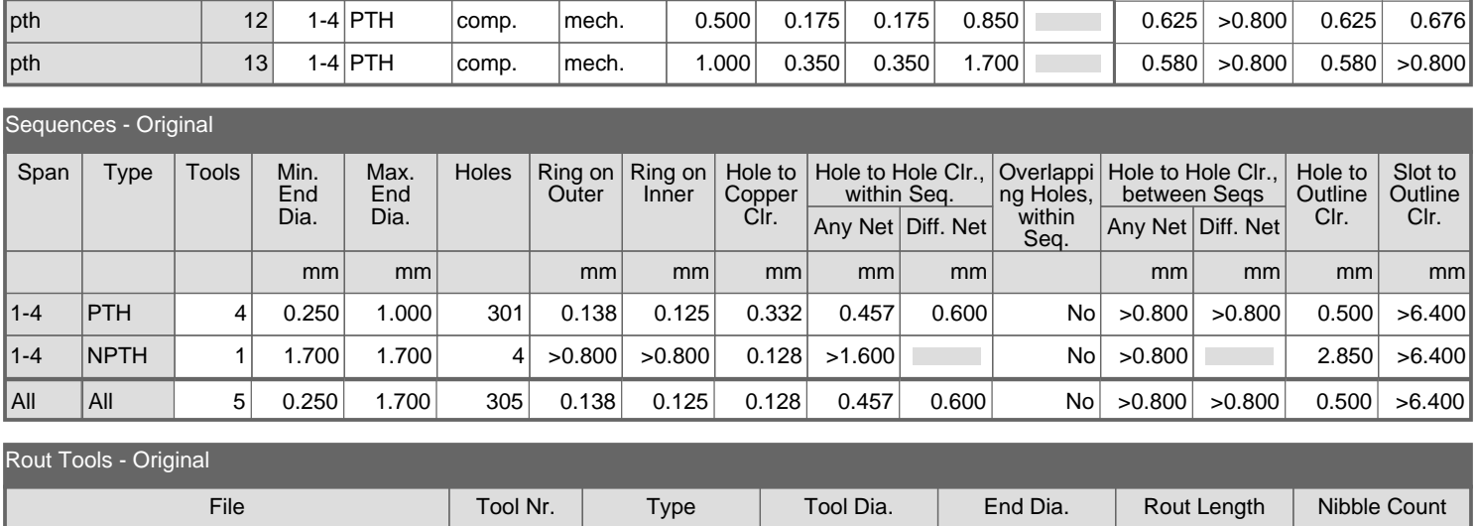
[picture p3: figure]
pth; 1-4 PTH; comp.; mech.; Sequences - Original; Span; Type; Tools; Min.; End Dia.; Max. End Dia.; Holes Ring on Outer; Ring on Inner; Hole to Copper Clr.; Hole to Hole Clr., within Seq.; Overlappi ng Holes, within Seq.; Hole to Hole Clr., between Seqs; Hole to Outline Clr.; Slot to Outline; Clr. Any Net Diff. Net; Any Net Diff. Net; PTH; NPTH; All; Rout Tools - Original; File; Tool Nr.; Tool Dia.; Rout Length; Nibble Count

mm | mm | mm

Routed Holes - Original

File | Hole Nr. | Instances | X Size | Y Size | Rout Length | Nibble Count
mm | mm | mm

Sequences Analysis - Original

File | Pos. Stacked
Vias
| Overlap ped Vias | Via Plug Clr.
Top Tool | Bottom Tool
Top Drill File | Tool Nr. | Dia. | Bottom Drill File Tool Nr. | Dia.
| | mm | | mm | | mm
Report Generated on | Apr 10, 2025, 4:57:56 PM | Customer
Board Id | | Article Id

SMD (Incl. BGA) - Original

SMD (Incl. BGA) | SMD (Excl.
BGA)

BGA

Side | Pads | Min. Pad Pitch of Min.
Pad

Solder
Mask
Defined
Pads
Pads | Pads | Min. Pad | Min. Pitch | All Tracks Centered

Drilled Pads

mm | mm | mm | mm
Top | 277 | 0.240 | 0.500 | 0 | 277 | 0

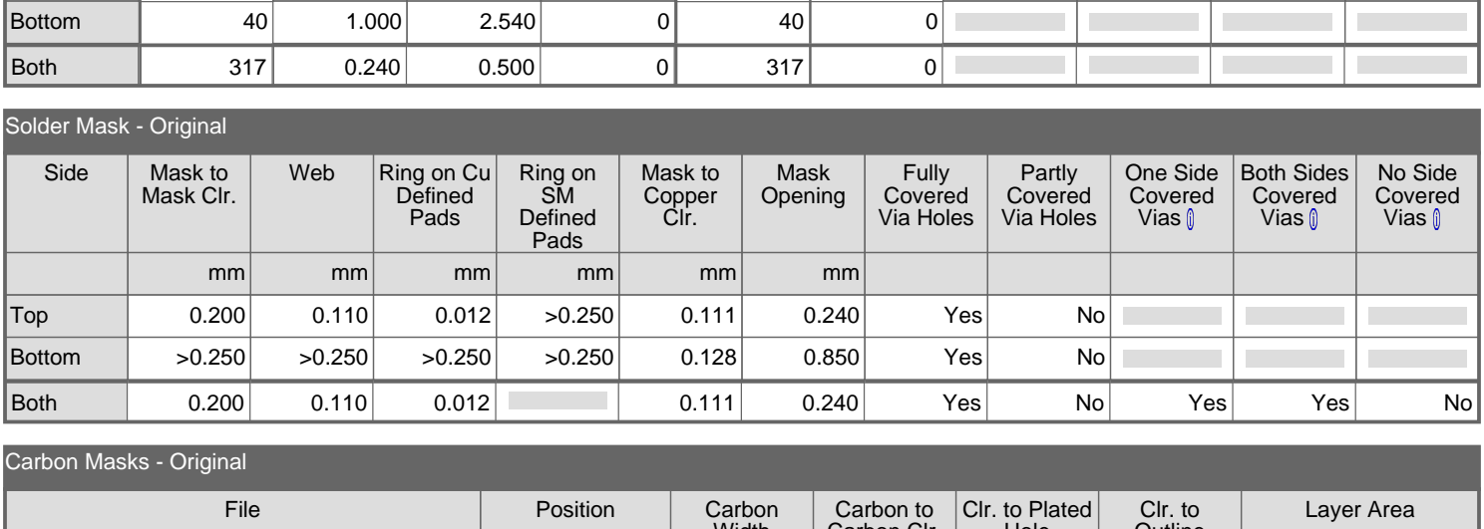
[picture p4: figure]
Bottom; Both; Solder Mask - Original; Side; Mask to; Mask Clr.; Web; Ring on Cu; Defined Pads; Ring on SM Defined Pads; Mask to Copper Clr.; Mask Opening; Fully Covered Via Holes; Partly Covered Via Holes; One Side Covered Vias; Both Sides Covered Vias; No Side Covered Vias; Top; Yes; Carbon Masks - Original; File; Position; Carbon; Carbon to; Clr. to Plated; Clr. to; Layer Area

Width

Carbon Clr.

Hole

Outline
mm | mm | mm | mm | dm² | %

Peeloff Masks - Original

File | Position | Min.
Peelable
Width

Peelable to
Peelable Clr.

Clr. to Plated
Hole

Clr. to
Outline

Layer Area

mm | mm | mm | mm | dm² | %

Legend Layers - Original

File | Position | Legend Width | Legend to
Legend Clr.

Legend to
(Comp/SMD/BGA)
Pad Clr.

Layer Area

| | mm | mm | mm | dm² | %
silk-top | top | 0.100 | 0.043 | 0.140 | 0.0178 | 4
silk-bot | bottom | 0.120 | 0.187 | 0.200 | 0.0012 | 0

Gold Layers - Original

File | Position | Gold to Gold Clr. | Clr. to Outline | Layer Area
| | | mm | mm | dm² | %

Heatsink Layers - Original

File | Position | Heatsink to
| | Heatsink Clr.
Clr. to Outline | Layer Area
| | | mm | mm | dm² | %
Board Id | Article Id

Scoring - Minimum Clearance - Original

No license to generate this information.

Bare Board Test - Original

Side | Testable Points (TPs)
Max. TP Density | SMD Pads | Min. SMD Pad | Pitch of Min.
SMD Pad

Edge Connector
Fingers

Number of Nets

| | TP/dm² | | | mm | | mm
Top | 322 | 2701 | | 277 | 0.240 | | 0.500 | | 0
Bottom | 57 | 679 | | 40 | 1.000 | | 2.540 | | 0
Both | 379 | 2701 | | 317 | 0.240 | | 0.500 | | 0 | | 110

DFM Classes - Original

Standard | Advanced
| | | 1 | 2 | 3 | 4 | 5 | 6 | 7 | 8 | 9
Track & Gap | Min Clearance (Track-Track / Track-Pad / Pad-Pad) | 0.142 | 0.300 | 0.250 | 0.200 | 0.150 | 0.130 | 0.120 | 0.100 | 0.075 | 0.060
| Min Track Width / Thermal Gap | 0.237 | 0.300 | 0.250 | 0.200 | 0.150 | 0.130 | 0.120 | 0.100 | 0.075 | 0.060

Ring for IPC Class

2 | Outer Min Layer Annular Ring | 0.138 | 0.250 | 0.220 | 0.200 | 0.150 | 0.130 | 0.120 | 0.100 | 0.075 | 0.060
| Inner Min Layer Annular Ring | 0.125 | 0.250 | 0.220 | 0.200 | 0.150 | 0.130 | 0.120 | 0.100 | 0.075 | 0.060
Aspect Ratio | Max Aspect Ratio for Plated Hole
6.400 | 8.000 | 8.000 | 8.000 | 8.000 10.000 10.000 10.000 10.000 10.000
Drill - Cu | Distance PTH to PTH | 0.457 | 0.600 | 0.500 | 0.400 | 0.350 | 0.300 | 0.300 | 0.275 | 0.250 | 0.230
| Distance NPTH to Cu on inner layers | 0.128 | 0.250 | 0.250 | 0.200 | 0.200 | 0.150 | 0.150 | 0.150 | 0.100 | 0.100
| Distance NPTH to Cu on outer layers | 0.128 | 0.250 | 0.250 | 0.200 | 0.200 | 0.150 | 0.150 | 0.150 | 0.100 | 0.100
Cu Thickness | Max Cu Thickness that can be etched | | 0.175 | 0.140 | 0.105 | 0.070 | 0.070 | 0.035 | 0.035 | 0.035 | 0.017
Solder Mask | Solder Mask Annular Ring | 0.012 | 0.100 | 0.075 | 0.050 | 0.050 | 0.050 | 0.050 | 0.040 | 0.030 | 0.010
| Solder Mask SolderWeb | 0.110 | 0.150 | 0.125 | 0.100 | 0.100 | 0.100 | 0.100 | 0.080 | 0.075 | 0.075

Anomalies - Original

Outline cutout slightly clips functional copper in layer 'top' Outline cutout slightly clips functional copper in layer 'in2'
Outline cutout slightly clips functional copper in layer 'in3'
Outline cutout slightly clips functional copper in layer 'bot'
[AutoClean] Functional copper outside or touching outline in layer 'top' [AutoClean] Functional copper outside or touching outline in layer 'in2' [AutoClean] Functional copper outside or touching outline in layer 'in3' [AutoClean] Functional copper outside or touching outline in layer 'bot' Functional copper outside or touching outline in layer 'top'
Functional copper outside or touching outline in layer 'in2'
Functional copper outside or touching outline in layer 'in3'
Functional copper outside or touching outline in layer 'bot'
Board Id | Article Id

Input Remarks - Original

Gerber import: Invalid coincident draw, continuing without cleanup 'copper-bottom.pho'
Gerber import: Self-intersecting contours are detected, continuing with an interpretation of the contours. 'copper-bottom.pho' (at line 6565)
Gerber import: Invalid coincident draw, continuing without cleanup 'copper-inner-1.pho'
Gerber import: Self-intersecting contours are detected, continuing with an interpretation of the contours. 'copper-inner-1.pho' (at line 3426)
Gerber import: Invalid contour, continuing with an interpretation. Cannot be cleaned up automatically. Must be cleaned up manually. 'copper-inner-1.pho' (at line 5974)
Gerber import: Invalid coincident draw, continuing without cleanup 'copper-inner-2.pho'
Gerber import: Self-intersecting contours are detected, continuing with an interpretation of the contours. 'copper-inner-2.pho' (at line 4107)
Gerber import: Invalid coincident draw, continuing without cleanup 'copper-top.pho'
Gerber import: Self-intersecting contours are detected, continuing with an interpretation of the contours. 'copper-top.pho' (at line 8852) Gerber Job File import: DISCREPANCY: Extra top layers mismatch between Gerber Job File and current job stackup.

Customer and Job Identification - Original

Customer
Customer | Contact Person
Email

Customer and Job Identification - Original

Job
Article Id | | Board Id
DPMX Output Path | CH

Comments - Original

Board Id | Article Id

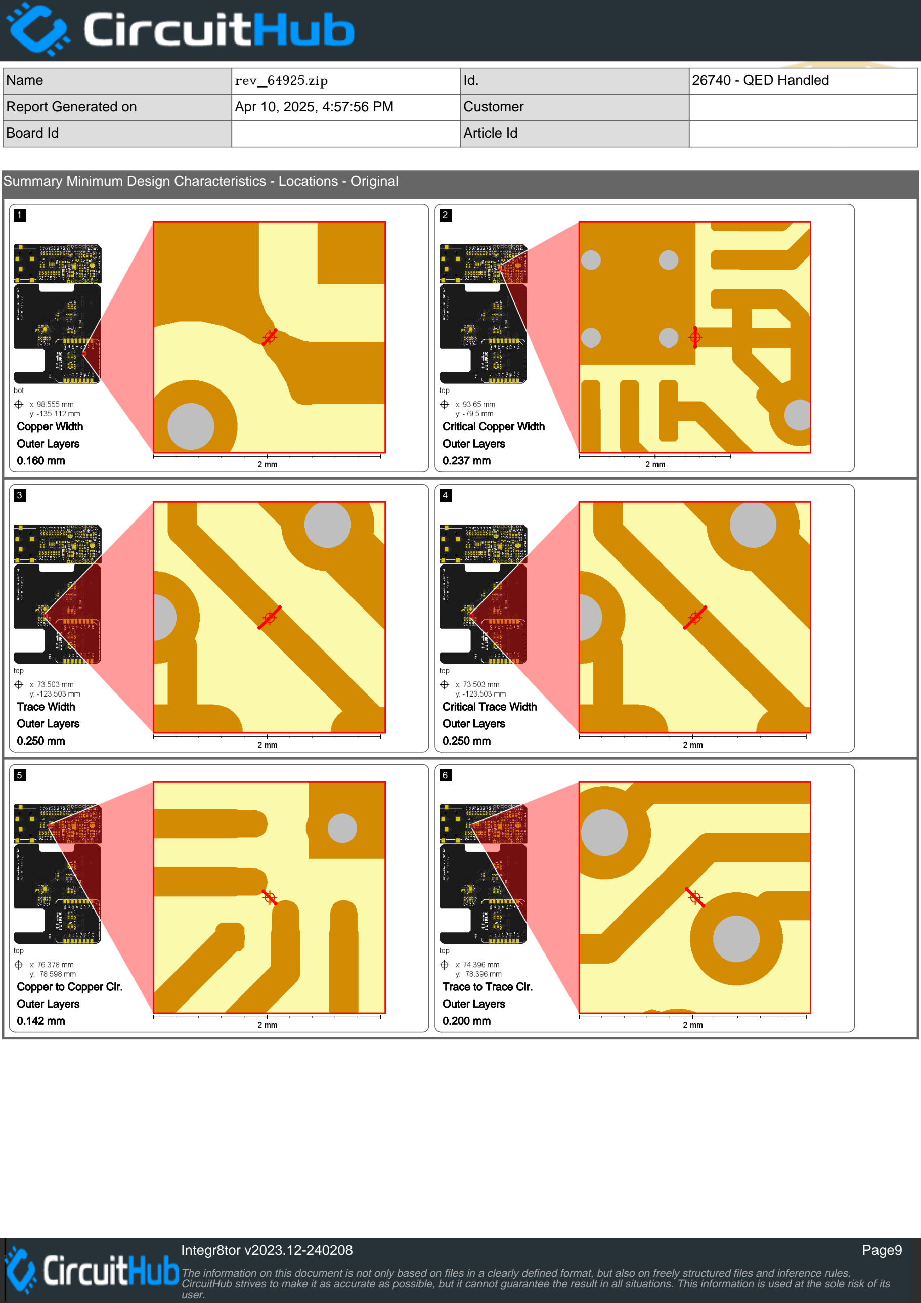
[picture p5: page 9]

1 | 2
3 | 4
5 | 6

Summary Minimum Design Characteristics - Locations - Original

Copper Width
Outer Layers
0.160 mm

Critical Copper Width
Outer Layers
0.237 mm

Trace Width
Outer Layers
0.250 mm

Critical Trace Width
Outer Layers
0.250 mm

Copper to Copper Clr.
Outer Layers
0.142 mm

Trace to Trace Clr.
Outer Layers
0.200 mm
Board Id | Article Id

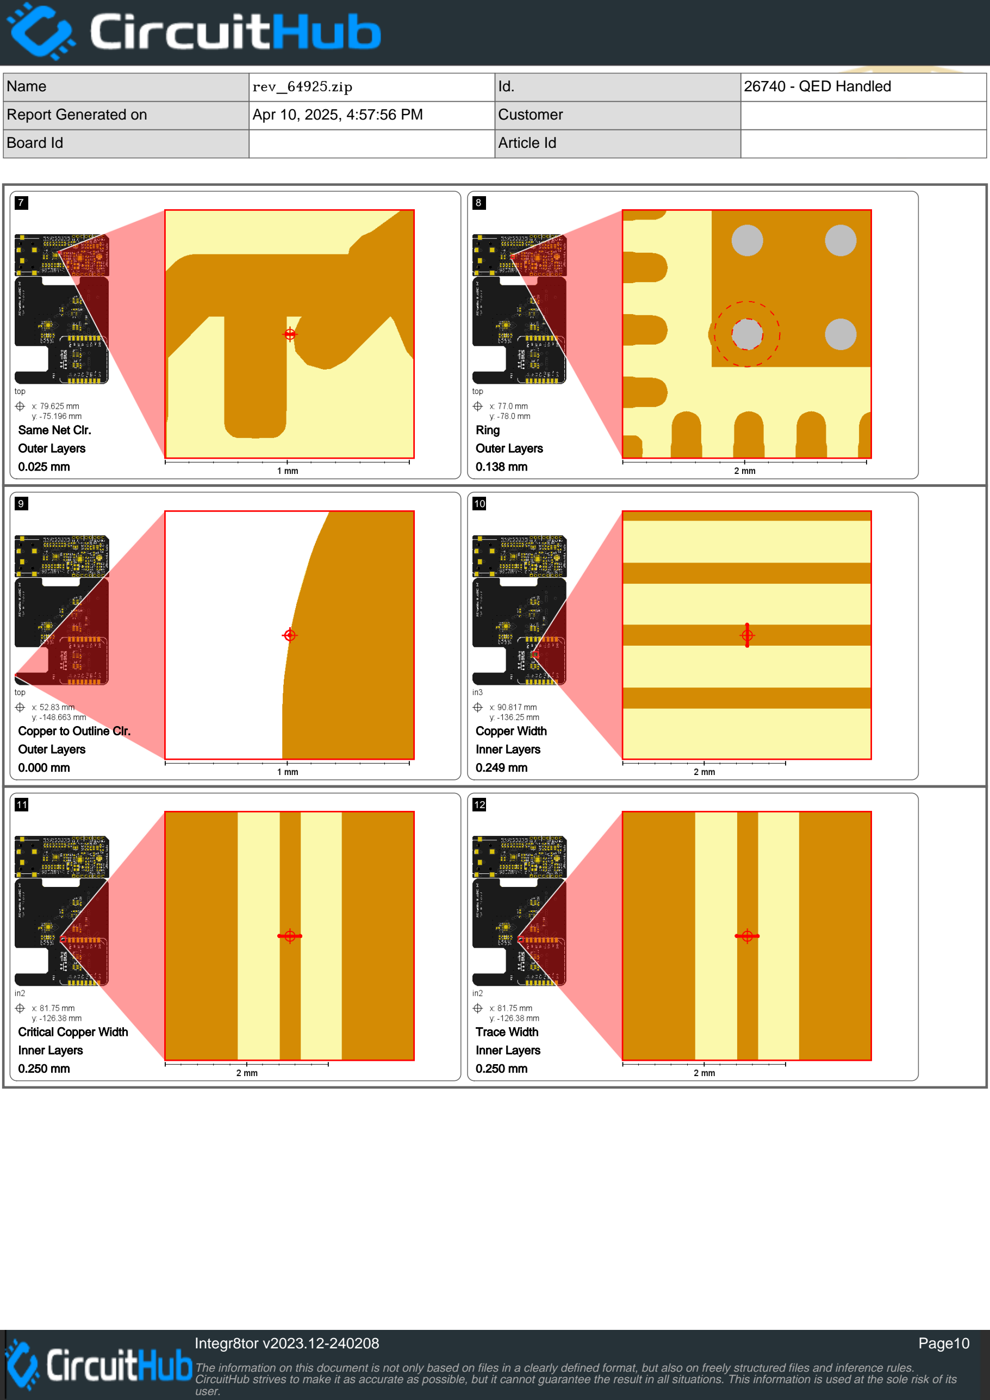
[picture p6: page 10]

7 | 8
9 | 10
11 | 12

Same Net Clr.
Outer Layers
0.025 mm

Ring
Outer Layers
0.138 mm

Copper to Outline Clr.
Outer Layers
0.000 mm

Copper Width
Inner Layers
0.249 mm

Critical Copper Width
Inner Layers
0.250 mm

Trace Width
Inner Layers
0.250 mm
Board Id | Article Id

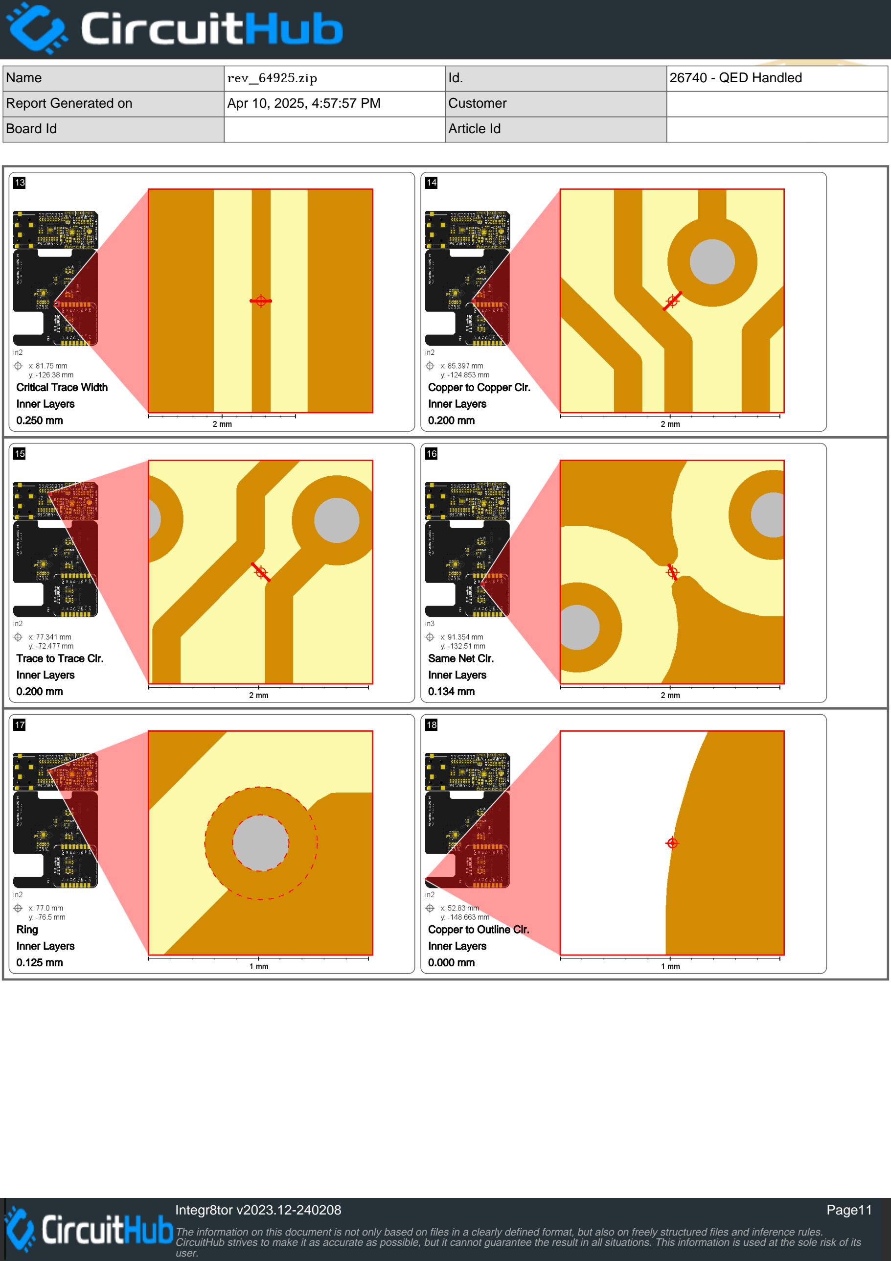
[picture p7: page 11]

13 | 14
15 | 16
17 | 18

Critical Trace Width
Inner Layers
0.250 mm

Copper to Copper Clr.
Inner Layers
0.200 mm

Trace to Trace Clr.
Inner Layers
0.200 mm

Same Net Clr.
Inner Layers
0.134 mm

Ring
Inner Layers
0.125 mm

Copper to Outline Clr.
Inner Layers
0.000 mm
Report Generated on | Apr 10, 2025, 4:57:57 PM | Customer
Board Id | | Article Id

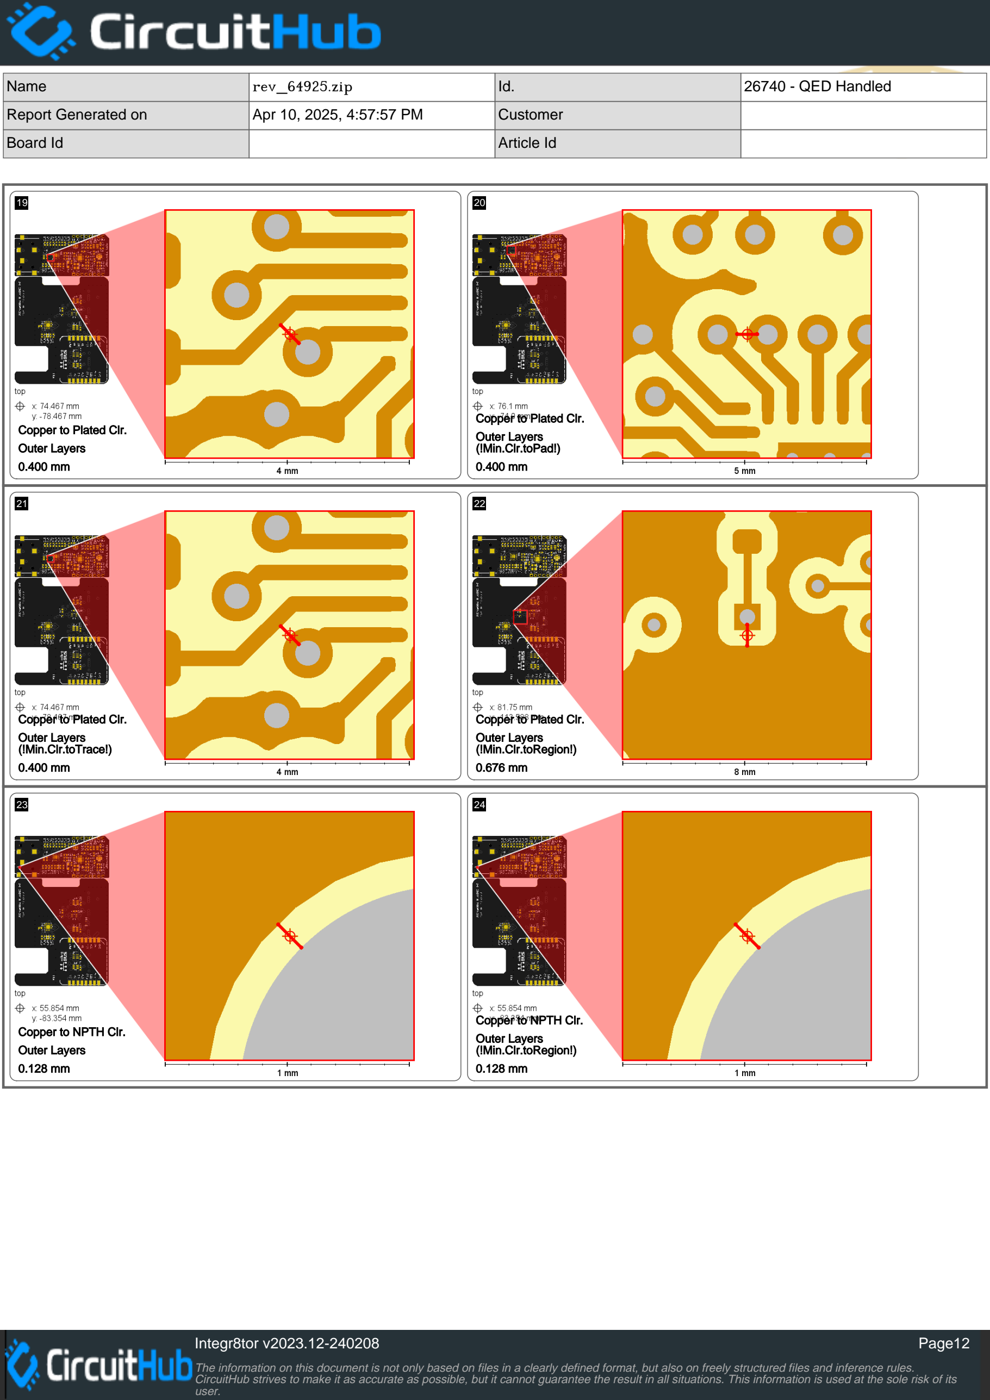
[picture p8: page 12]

19 | 20
21 | 22
23 | 24

Copper to Plated Clr.
Outer Layers
0.400 mm

Copper to Plated Clr.
Outer Layers
(!Min.Clr.toPad!)
0.400 mm

Copper to Plated Clr.
Outer Layers
(!Min.Clr.toTrace!)
0.400 mm

Copper to Plated Clr.
Outer Layers
(!Min.Clr.toRegion!)
0.676 mm

Copper to NPTH Clr.
Outer Layers
0.128 mm

Copper to NPTH Clr.
Outer Layers
(!Min.Clr.toRegion!)
0.128 mm
Report Generated on | Apr 10, 2025, 4:57:57 PM | Customer
Board Id | | Article Id

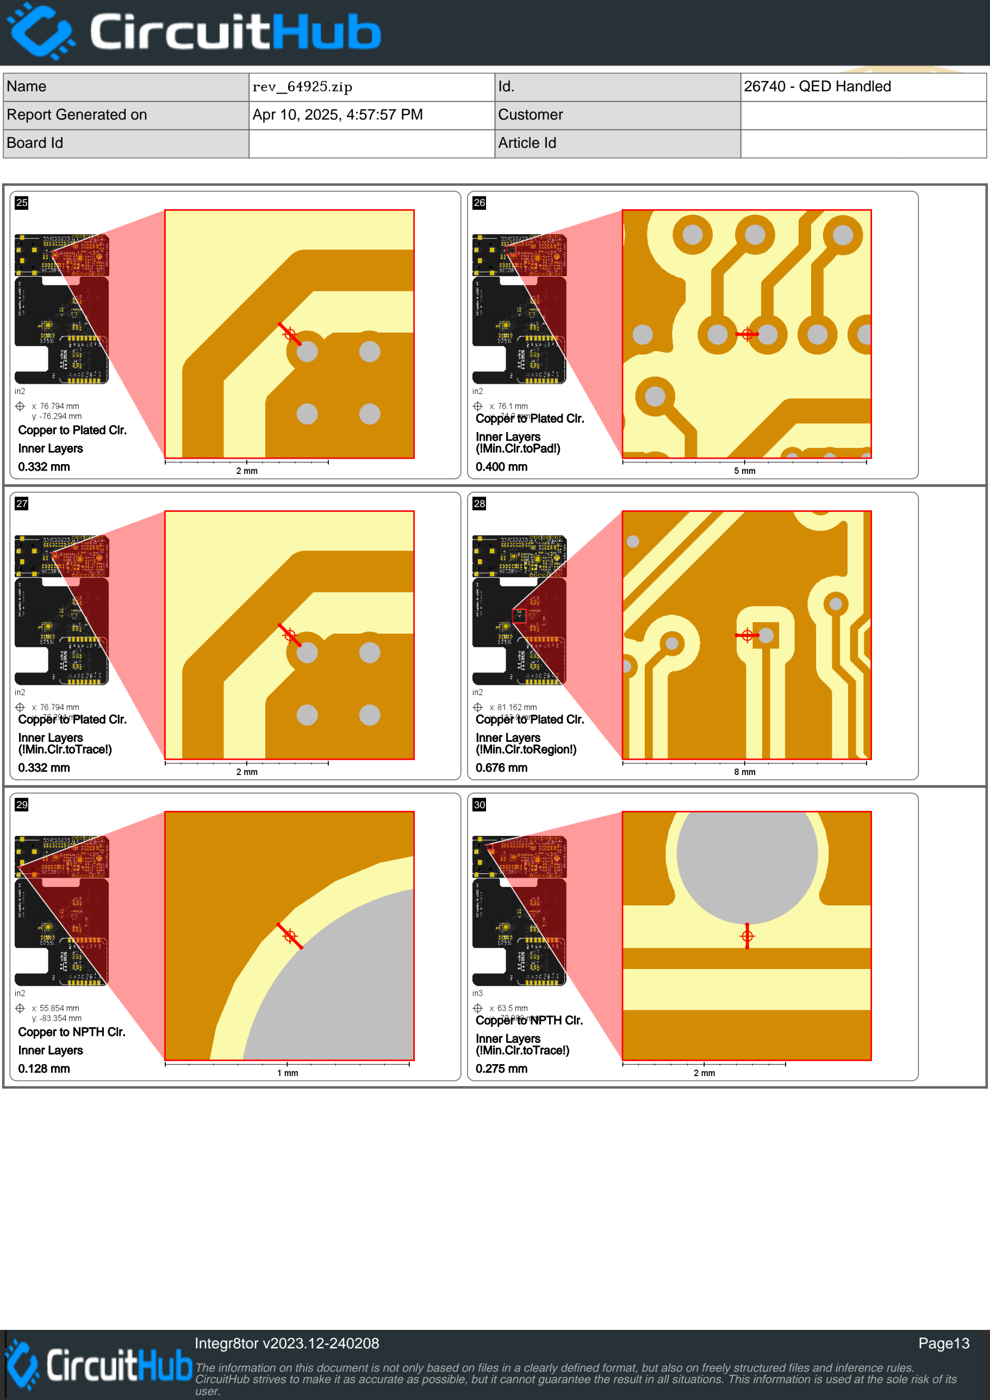
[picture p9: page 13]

25 | 26
27 | 28
29 | 30

Copper to Plated Clr.
Inner Layers
0.332 mm

Copper to Plated Clr.
Inner Layers
(!Min.Clr.toPad!)
0.400 mm

Copper to Plated Clr.
Inner Layers
(!Min.Clr.toTrace!)
0.332 mm

Copper to Plated Clr.
Inner Layers
(!Min.Clr.toRegion!)
0.676 mm

Copper to NPTH Clr.
Inner Layers
0.128 mm

Copper to NPTH Clr.
Inner Layers
(!Min.Clr.toTrace!)
0.275 mm
Report Generated on | Apr 10, 2025, 4:57:57 PM | Customer
Board Id | | Article Id

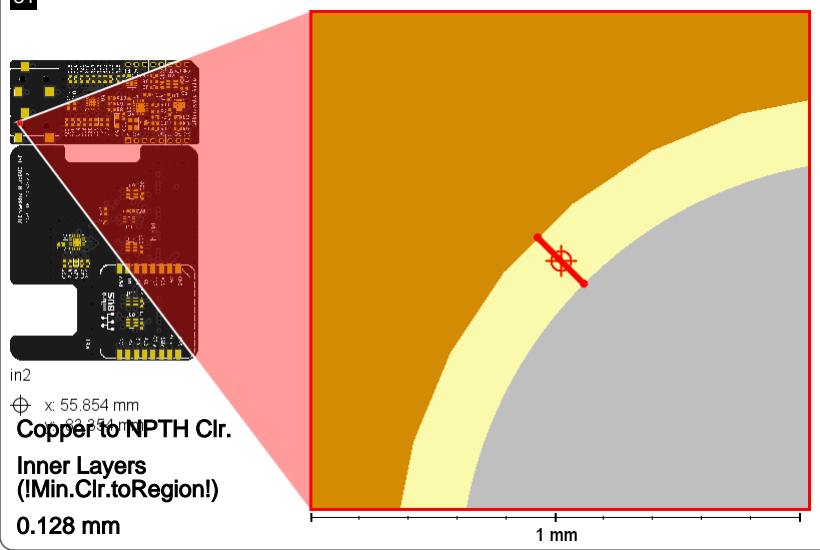
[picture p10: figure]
Copper to NPTH Clr. Inner Layers (!Min.Clr.toRegion!) 0.128 mm

31

Report Generated on | Apr 10, 2025, 4:57:57 PM | Customer
Board Id | | Article Id

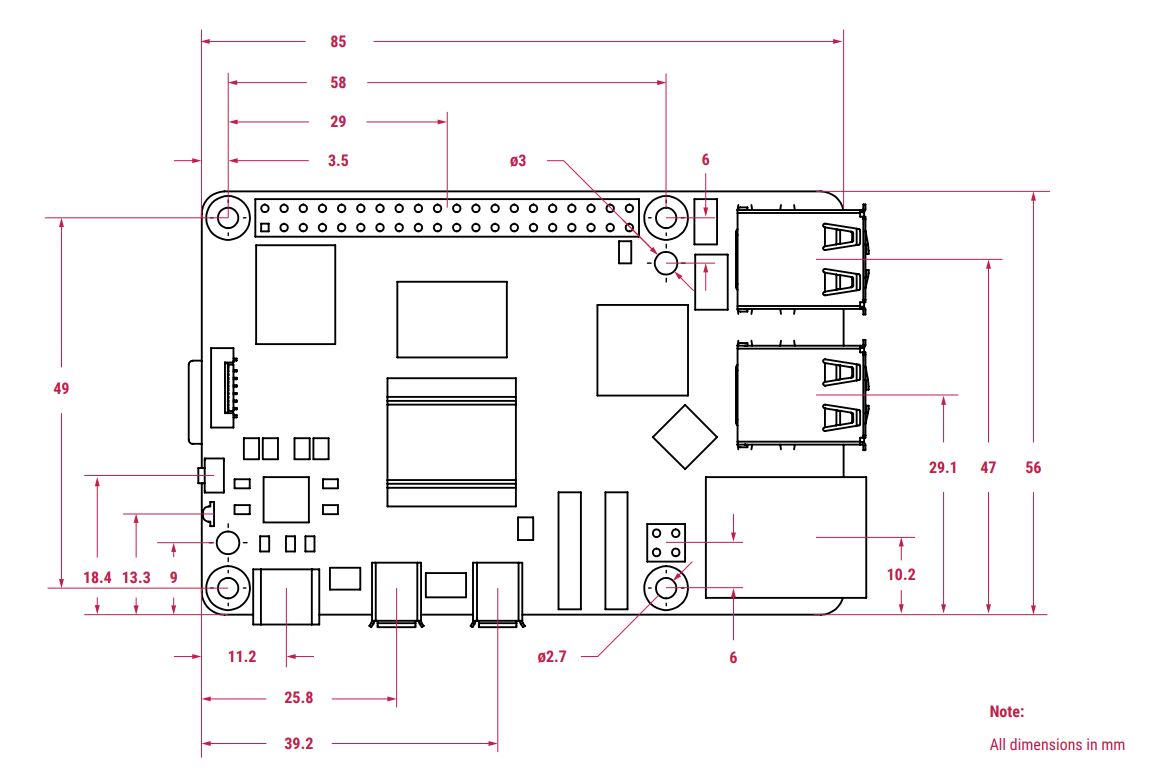
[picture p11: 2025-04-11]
reference/Raspberry+Pi+5+Technical+Drawing.JPG

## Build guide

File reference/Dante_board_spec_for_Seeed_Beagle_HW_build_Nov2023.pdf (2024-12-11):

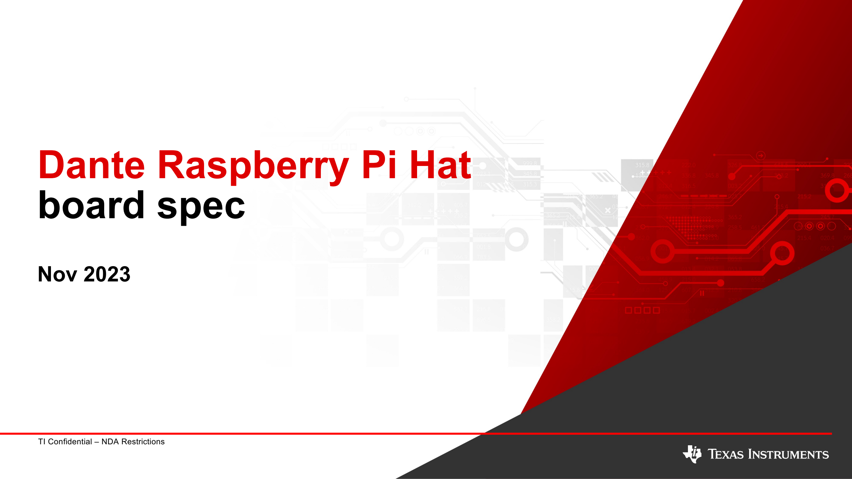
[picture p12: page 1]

TI Confidential – NDA Restrictions

# Dante Raspberry Pi Hat board spec

# Nov 2023

AM6x Starter Kit | Dante Daughter card

# DANTE Raspberry HAT for AM62/AM62A/AM68A/AM69A starter kits

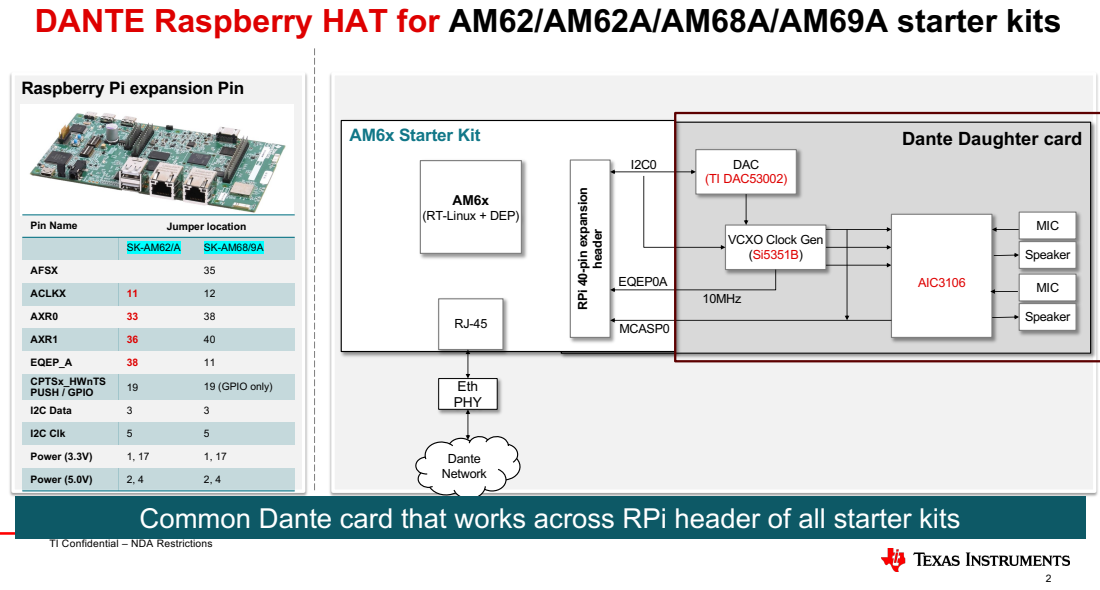
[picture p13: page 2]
Eth PHY; Dante Network; header; DAC (TI DAC53002); EQEP0A; 10MHz; AIC3106; MCASP0; MIC; Speaker; Pin Name; Jumper location; AFSX; ACLKX; AXR0; AXR1; EQEP_A; CPTSx_HWnTS; PUSH / GPIO; 19 (GPIO only); I2C Data; I2C Clk; Power (3.3V); Power (5.0V)

Raspberry Pi expansion Pin

RPi 40-pin expansion

(RT-Linux + DEP)

VCXO Clock Gen

Common Dante card that works across RPi header of all starter kits

# Raspberry Pi pinout on SK-AM62

3

Ball | Pin Name | Use Case
| | Function | Mux
| | | Mode | Directio
| | | | n | EVM Location | Instructions/info on AM62x SK EVM
D20 | AFSX | Frame Sync (TX) | 0 | Input | De-pop R32, blue-
| | | | | wire required
B20 | ACLKX | Bit Clock (TX) | 0 | Input | J3.11 | 10k pull-up to 3.3V on the AM62x SK EVM
E18 | AXR0 | Serializer 0 | 0 | Input | J3.33 | Directly connected to User Expansion Connector
B18 | AXR1 | Serializer 1 | 0 | Input | J3.36 | 10k pull-up to 3.3V on the AM62x SK EVM
A16 | I2C0.SDA | I2C Data | 0 | I/0 | J3.3 | 4.7k pull-up to 3.3V on the AM62x SK EVM
B16 | I2C0.SCL | I2C Clock | 0 | Output | J3.5 | 4.7k pull-up to 3.3V on the AM62x SK EVM
B19 | EQEP0_A | 10MHz FB CLK
| | input/counter | 8 | Input | J3.38 | Connected to User Expansion Connector through a mux whose SEL pin is controlled through an
| | | | | | I/O expander (enable on I/O expander P12, SEL on I/O expander P25)
B13 | HW1TSPUSH/GPIO1_
| 18 | LR Clock
| | feedback | 1 or 7 | Input | J3.19 | Directly connected to User Expansion Connector
n/a | - | 3.3V | | | J3.1 & J3.17 | Enabled through an enable pin controlled by an I/O expander (P5 output on the expander)
n/a | - | 5V | | | J3.2 & J3.4 | Enabled through an enable pin controlled by an I/O expander (P6 output on the expander)

# Jason to review this table

# Dante board Reference Schematic

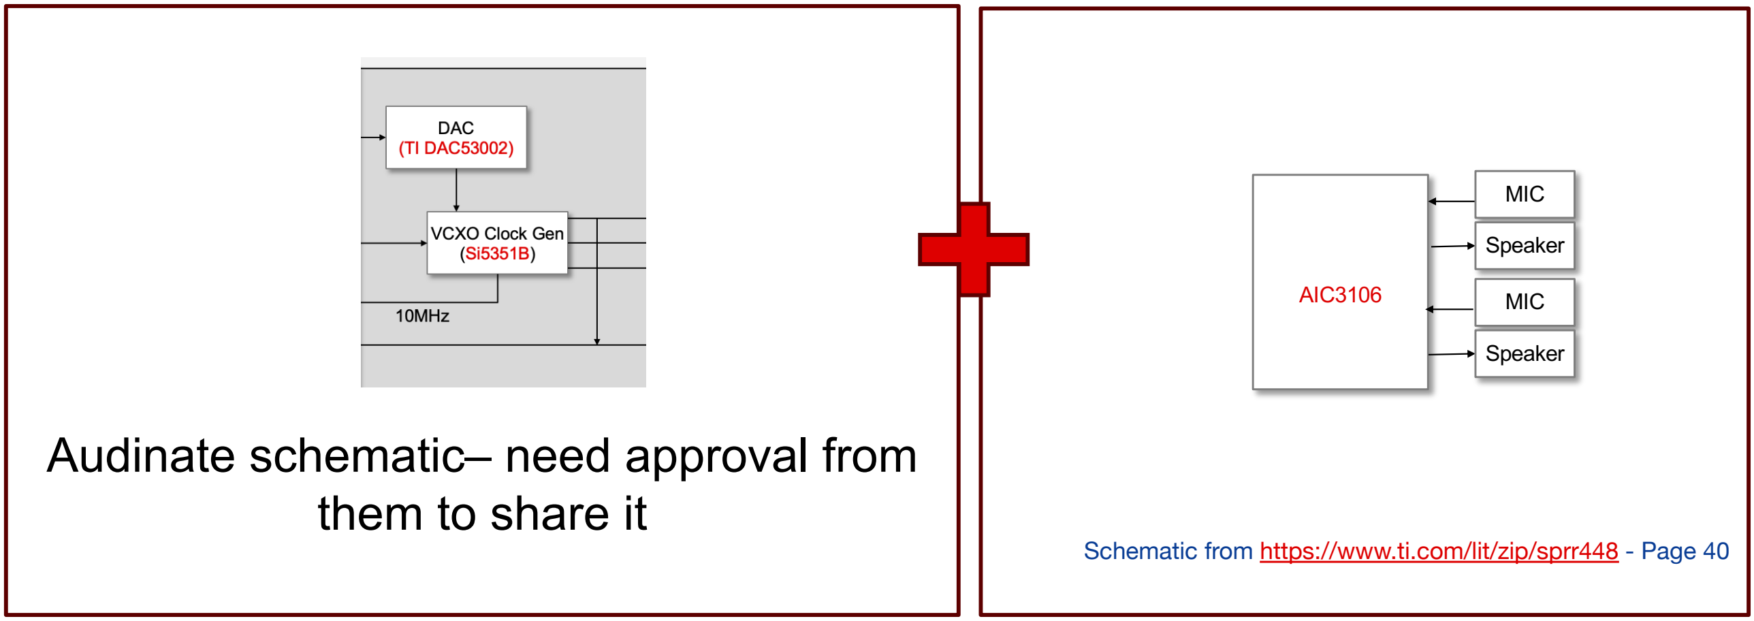
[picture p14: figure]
Audinate schematic– need approval from them to share it; AIC3106; MIC; Speaker

4

# Overall Schematic: Dante ref design (Left above) + AM62x-SK ref design (right above)

Schematic from https://www.ti.com/lit/zip/sprr448 - Page 40

# Dante board Reference Schematic

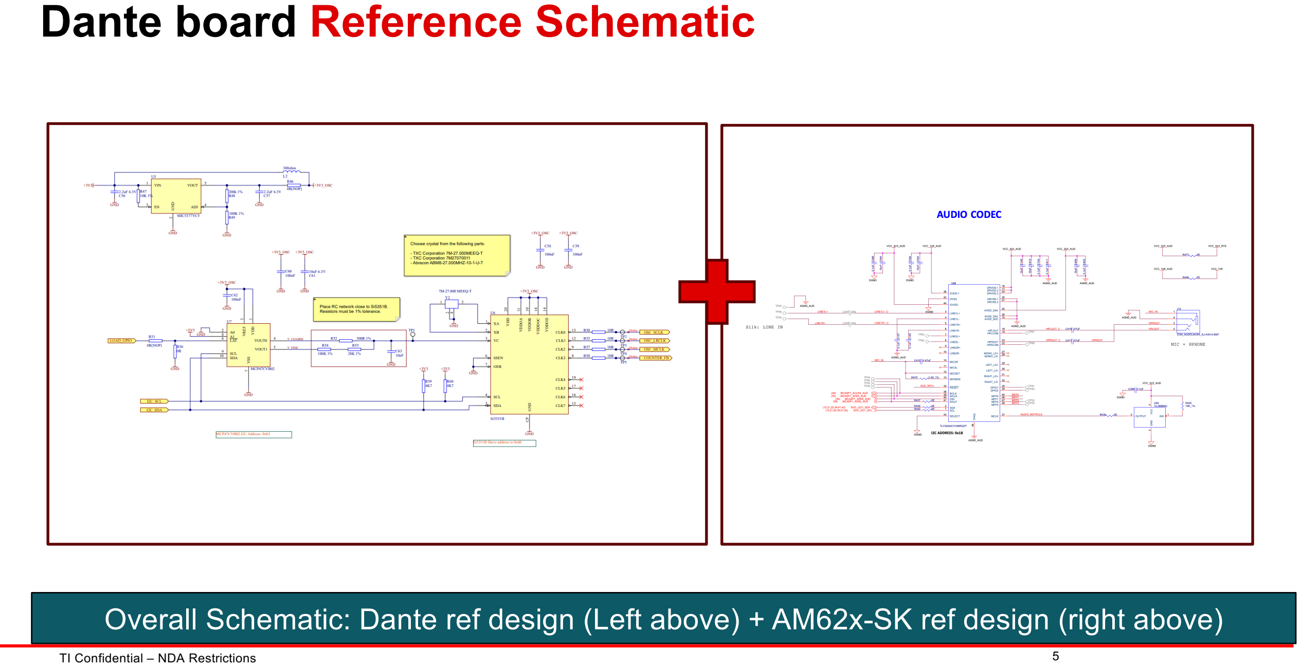
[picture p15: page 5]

5

# Overall Schematic: Dante ref design (Left above) + AM62x-SK ref design (right above)

# Clock schematic | from Audinate

6

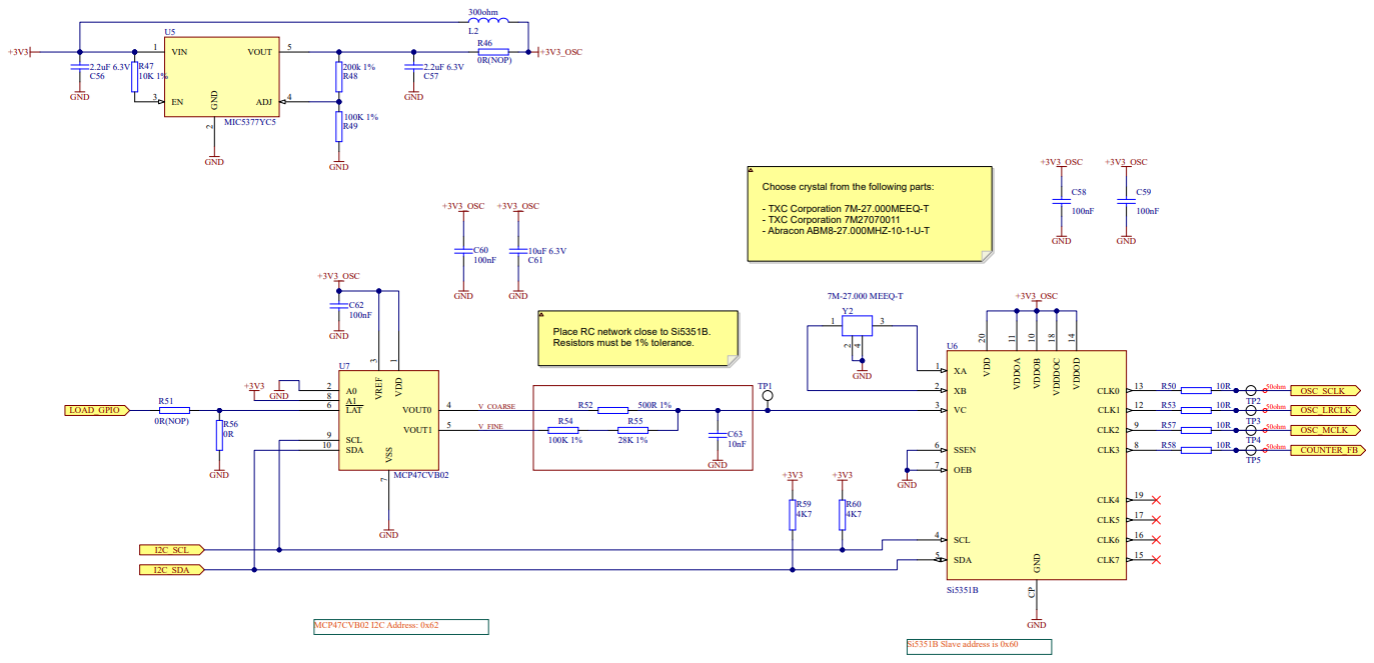
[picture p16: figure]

# Codec and AFE schematic

7

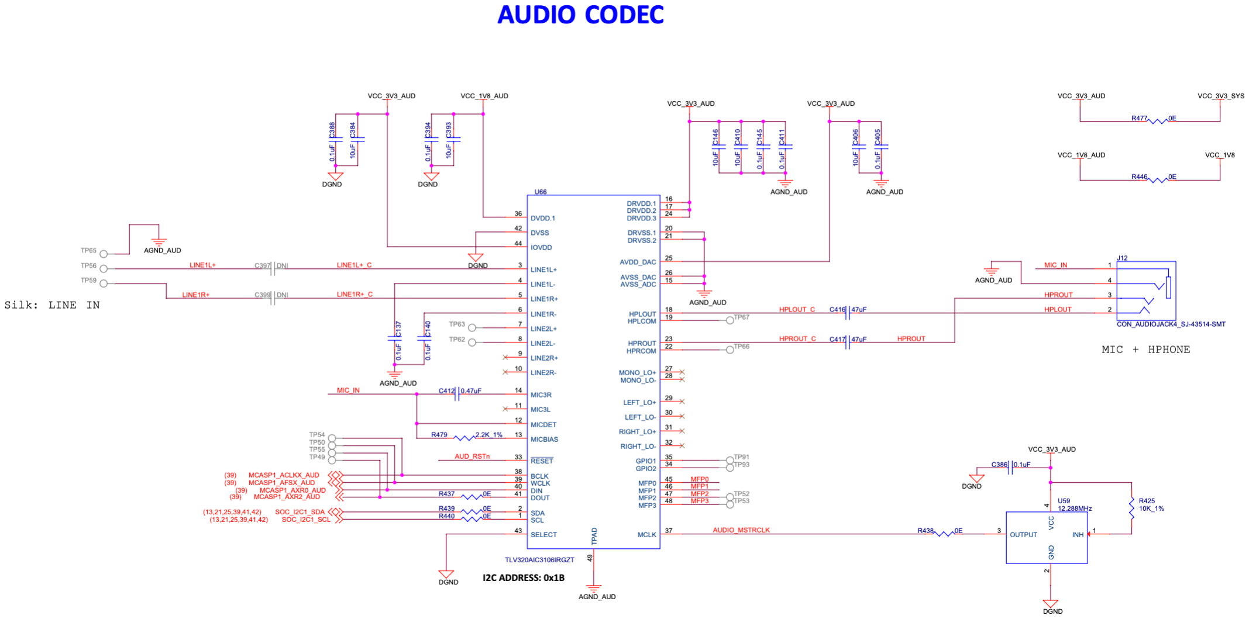
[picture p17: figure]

# RPi connector pins to use | AM62 vs AM68/9

8

Pin Name | SK-AM62 | SK-AM68/9
AFSX | | 35
ACLKX | 11 | 12
AXR0 | 33 | 38
AXR1 | 36 | 40
EQEP_A | 38 | 11
CPTSx_HWnTSPUSH / GPIO | 19 | 19 (GPIO only)
I2C Data | 3 | 3
I2C Clk | 5 | 5
Power (3.3V) | 1, 17 | 1, 17
Power (5.0V) | 2, 4 | 2, 4

# Common HAT | Pin differences taken care with HW mux switch

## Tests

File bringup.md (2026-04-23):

# Bring-up notes/checklist

## Audio add-on

### Initial power

#### 3.3V only

- [x] 3.3V: 2-7mA
- [x] PWM/BIT: 0V
- [x] RST/WRD: 0V
- [x] PICO/TS: 0V
- [x] POCI/CNT: 0V
- [x] CS: 3.3V
- [x] AN/DI: 0V
- [x] INT/DO: 0V
- [x] SCL: 0V
- [x] SDA: 0V
- [x] 5V: 0V
- [x] TP1: 0V
- [x] Y1: 0V
- [x] MCLK: 0V

#### 5V only

- [x] 5V: 25-27mA
- [x] 3V3-OSC: 3.32V, some noise
- [x] PWM/BIT: 0V
- [x] RST/WRD: 0V
- [x] PICO/TS: 0V
- [x] POCI/CNT: 0V
- [x] CS: 3.3V
- [x] AN/DI: 0V
- [x] INT/DO: 0V
- [x] SCL: 0V
- [x] SDA: 0V
- [x] 5V: 0V
- [x] TP1: 0V (with noise)
- [x] Y1: 27MHz sine wave, with some anomolies
- [x] MCLK: 0V

#### I2C

Providing 3.3V and 5V

```console
beagle@beagle:~$ ls -l /dev/play/mikrobus/i2c 
lrwxrwxrwx 1 root root 11 Feb 14 17:57 /dev/play/mikrobus/i2c -> ../../i2c-3
beagle@beagle:~$ i2cdetect -y -r 3
     0  1  2  3  4  5  6  7  8  9  a  b  c  d  e  f
00:                         -- -- -- -- -- -- -- -- 
10: -- -- -- -- -- -- -- -- -- -- -- -- -- -- -- -- 
20: -- -- -- -- -- -- -- -- -- -- -- -- -- -- -- -- 
30: -- -- -- -- -- -- -- -- -- -- -- -- -- -- -- -- 
40: -- -- -- -- -- -- -- 47 48 -- -- -- -- -- -- -- 
50: 50 -- -- -- -- -- -- -- -- -- -- -- -- -- -- -- 
60: 60 -- -- -- -- -- -- -- -- -- -- -- -- -- -- -- 
70: -- -- -- -- -- -- -- --             
```

### MSPM0 Zephyr bring-up and mux verification

This section captures the current working state, not the older failed
bring-up attempts.

#### Reproducible starting point

Use this starting point for a fresh system:

- BeagleY-AI host
- mikroBUS HAT installed
- audio board installed on the mikroBUS socket
- no validation jumpers fitted
- no MSPM0 GPIO overlay applied
- no audio overlay applied
- no 1-wire EEPROM programming assumptions

The goal at this stage is only:

1. build the MSPM0 firmware
2. flash it over `/dev/hat/mcu_i2c0`
3. verify the raw I2C bus without any overlay help

#### Host setup used

- BeagleY-AI host
- Local Zephyr workspace checked out alongside this repository
- Local Zephyr branch `audio-board` with MSPM0L110x GPIO support merged
- `bb-imager-rs` with `flash zepto` support and GPIO-assisted BSL entry

#### Build the firmware image

```console
REPO_ROOT="$(git rev-parse --show-toplevel)"
ZEPHYR_TOOLCHAIN_VARIANT=gnuarmemb \
GNUARMEMB_TOOLCHAIN_PATH=/usr \
west build -p always \
  -d "${REPO_ROOT}/build/mspm0-zephyr" \
  -b mikrobus_hat \
  "${REPO_ROOT}/firmware/mspm0-gpo-extender/app" \
  -- \
  -G'Unix Makefiles' \
  -DBOARD_ROOT="${REPO_ROOT}/firmware"
```

Artifacts:

- `build/mspm0-zephyr/zephyr/zephyr.hex`
- `build/mspm0-zephyr/zephyr/zephyr.bin`

#### Flash the image

Current working command:

```console
REPO_ROOT="$(git rev-parse --show-toplevel)"
BB_IMAGER_CLI="${BB_IMAGER_CLI:-../bb-imager-rs/target/debug/bb-imager-cli}"
"${BB_IMAGER_CLI}" --verbose flash zepto \
  "${REPO_ROOT}/build/mspm0-zephyr/zephyr/zephyr.hex" \
  --reset-gpio GPIO24 \
  --bsl-gpio GPIO25 \
  /dev/hat/mcu_i2c0
```

Notes:

- `GPIO24` is `MCU_RESET`
- `GPIO25` is `MCU_BOOTLOADER_SEL`
- `/dev/hat/mcu_i2c0` is the working host-visible MSPM0 I2C/BSL bus
- The repo-built `bb-imager-cli` supports `flash zepto`; a stale installed CLI may not
- Flash verify over this transport is still not fully trustworthy; `--no-verify`
  may be required if the CRC stage reports a false failure after program/write succeeds

#### Raw post-flash verification

Before using any overlay or Linux `pca953x` binding, verify the raw bus:

```console
i2cdetect -y -r 1
```

Expected result after a successful flash and return to normal boot:

- audio board devices still present at `0x47`, `0x50`, and `0x60`
- MSPM0 app present at `0x20`
- no `0x48`

Troubleshooting:

- if `0x20` appears as `UU`, a previous `pca953x` client is already bound and
  should be removed before treating the scan as a clean baseline:

```console
echo 0x20 | sudo tee /sys/bus/i2c/devices/i2c-1/delete_device
```

- if `0x48` is still present, the MSPM0 is still in ROM BSL and boot-state
  handling needs to be fixed before moving on
- keep overlays disabled until this raw-I2C check passes

#### What is verified on hardware

- Zephyr GPIO works on this board with the local `audio-board` Zephyr branch
- `PA19` / `PA20` were driven successfully and observed at `J6`
- The mux is controllable from the MSPM0:
  - with `AN_SEL=0` and `INT_SEL=0`, an `AN -> INT` short routed to host `GPIO13` and `GPIO16`
  - with `AN_SEL=1` and `INT_SEL=1`, the same short routed to host `GPIO20` and `GPIO21`
  - with `AN_SEL=0` and `PWM_SEL=0`, an `AN -> PWM` short routed to host `GPIO17`
  - with `AN_SEL=0` and `PWM_SEL=1`, the same short routed to host `GPIO18`
  - with `AN_SEL=0`, the `AN -> MISO` combinations measured as:
    - `CIPO_SEL_0=0`, `CIPO_SEL_1=0` -> no host path selected
    - `CIPO_SEL_0=0`, `CIPO_SEL_1=1` -> host `GPIO20`
    - `CIPO_SEL_0=1`, `CIPO_SEL_1=0` -> host `GPIO16`
    - `CIPO_SEL_0=1`, `CIPO_SEL_1=1` -> host `GPIO17`

That proves:

- the updated flash path works
- the updated Zephyr MSPM0L1105 GPIO driver works
- the `AN_SEL`, `INT_SEL`, `PWM_SEL`, `CIPO_SEL_0`, and `CIPO_SEL_1`
  selectors are controllable in firmware
- `RST_SEL` was validated from HAT pin `7` (`GPIO4`), which is tied to the
  `J7` signal through `R23` (`0 ohm`)

#### I2C target validation

The current `app/` image emulates a `pca9538`-compatible 8-bit GPIO expander
at address `0x20`.

Validated on hardware:

- `0x20` ACKs in normal boot
- `0x48` disappears after returning `GPIO25` low and resetting with `GPIO24`
- direct register access works:

```console
i2ctransfer -y 1 w1@0x20 0x00 r4
# returns: INPUT OUTPUT POLARITY CONFIG
# example: 0xc0 0xff 0x00 0xff
```

- a standard Linux `gpio-pca953x` client also works:

```console
echo pca9538 0x20 | sudo tee /sys/bus/i2c/devices/i2c-1/new_device
gpiodetect
gpioinfo -c gpiochip3
echo 0x20 | sudo tee /sys/bus/i2c/devices/i2c-1/delete_device
```

- with `gpio-pca953x` bound, expander bits 2 and 3 control the measured mux
  route:
  - `2=0, 3=0` gives the `GPIO13 -> GPIO16` path
  - `2=1, 3=1` gives the `GPIO20 -> GPIO21` path

That is the current proof point that MSPM0 I2C target mode and PCA9538-style
host control are both working on hardware.

#### Current validation recipe

The validation flow is now scripted:

```console
./firmware/host-integration/linux/beagley-ai/validate-mux.sh sample an-int
```

With the audio board removed and `AN` shorted to `INT` on the mikroBUS socket,
that command produces:

```console
AN->INT low state (expect GPIO16=0 GPIO21=1): 0 1
AN->INT high state (expect GPIO16=1 GPIO21=0): 1 0
```

Manual hold-and-probe mode is also available:

1. Hold the host-side source levels apart:

```console
./firmware/host-integration/linux/beagley-ai/validate-mux.sh hold an-int low
```

Expected result:

- probe or read `GPIO16` low
- probe or read `GPIO21` high

Then:

```console
./firmware/host-integration/linux/beagley-ai/validate-mux.sh hold an-int high
```

Expected result:

- probe or read `GPIO16` high
- probe or read `GPIO21` low

- The script uses line names automatically when the host-side overlay is active.
- Without the overlay, it falls back to `gpiochip3` offsets for the expander.

#### Additional jumper setups for the remaining selectors

These setups are enough for host-side automated validation without probing the
MSPM0 pins directly:

- `AN -> PWM`

```console
./firmware/host-integration/linux/beagley-ai/validate-mux.sh sample an-pwm
```

Current measured output:

```console
AN->PWM low state (expect GPIO18=1 GPIO17=0): 1 0
AN->PWM high state (expect GPIO18=0 GPIO17=1): 0 1
```

- `AN -> MISO`

```console
./firmware/host-integration/linux/beagley-ai/validate-mux.sh sample an-miso
```

Current measured output:

```console
AN->MISO state 0 (CIPO_SEL_0=0 CIPO_SEL_1=0) -> GPIO16 GPIO20 GPIO17: 1 1 1
AN->MISO state 1 (CIPO_SEL_0=0 CIPO_SEL_1=1) -> GPIO16 GPIO20 GPIO17: 1 0 1
AN->MISO state 2 (CIPO_SEL_0=1 CIPO_SEL_1=0) -> GPIO16 GPIO20 GPIO17: 0 1 1
AN->MISO state 3 (CIPO_SEL_0=1 CIPO_SEL_1=1) -> GPIO16 GPIO20 GPIO17: 1 1 0
```

- `AN -> RST`

```console
./firmware/host-integration/linux/beagley-ai/validate-mux.sh sample an-rst
```

Expected output:

```console
AN->RST low state (expect GPIO19=1 GPIO4=0): 1 0
AN->RST high state (expect GPIO19=0 GPIO4=1): 0 1
```

Probe or read HAT pin `35` (`GPIO19`) and HAT pin `7` (`GPIO4`). HAT pin `7`
is tied to the same signal brought out at `J7` through `R23` (`0 ohm`), so it
is the preferred validation point on this PCB revision.

#### Current gaps before production firmware

- `RST_SEL` was measured and is opposite the original schematic assumption:
  - `RST_SEL=0` routes `WRD` to HAT pin `7` (`GPIO4`) / `J7`
  - `RST_SEL=1` routes `WRD` to HAT pin `35` (`GPIO19`)
- The current `mspm0-gpo-extender` app only exposes the mux selectors through
  the PCA9538 register model; host-profile policy is still future work

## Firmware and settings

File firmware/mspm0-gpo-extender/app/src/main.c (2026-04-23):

#include <zephyr/device.h>
#include <zephyr/drivers/gpio.h>
#include <zephyr/drivers/i2c.h>
#include <zephyr/kernel.h>
#include <zephyr/sys/util.h>

#define USER_NODE DT_PATH(zephyr_user)

#define PCA9538_I2C_ADDR      0x20
#define PCA9538_REG_INPUT     0x00
#define PCA9538_REG_OUTPUT    0x01
#define PCA9538_REG_POLARITY  0x02
#define PCA9538_REG_CONFIG    0x03
#define PCA9538_REG_MASK      0x03
#define PCA9538_HW_GPIO_COUNT 6
#define PCA9538_HW_MASK       GENMASK(PCA9538_HW_GPIO_COUNT - 1, 0)

struct pca9538_state {
	uint8_t output;
	uint8_t polarity;
	uint8_t config;
	uint8_t reg_ptr;
	bool reg_ptr_valid;
};

static const struct gpio_dt_spec mux_gpios[PCA9538_HW_GPIO_COUNT] = {
	GPIO_DT_SPEC_GET(USER_NODE, rst_wrd_sel_gpios),
	GPIO_DT_SPEC_GET(USER_NODE, pwm_bit_sel_gpios),
	GPIO_DT_SPEC_GET(USER_NODE, an_di_sel_gpios),
	GPIO_DT_SPEC_GET(USER_NODE, int_do_sel_gpios),
	GPIO_DT_SPEC_GET(USER_NODE, cipo_cnt_sel0_gpios),
	GPIO_DT_SPEC_GET(USER_NODE, cipo_cnt_sel1_gpios),
};

static const struct device *const i2c_target = DEVICE_DT_GET(DT_NODELABEL(i2c0));
static struct pca9538_state pca9538 = {
	.output = 0xffU,
	.polarity = 0x00U,
	.config = 0xffU,
	.reg_ptr = PCA9538_REG_INPUT,
	.reg_ptr_valid = false,
};

static int pca9538_apply_outputs(void)
{
	for (size_t i = 0; i < ARRAY_SIZE(mux_gpios); i++) {
		const struct gpio_dt_spec *spec = &mux_gpios[i];
		gpio_flags_t flags;
		bool is_input;
		bool level;
		int ret;

		if (!gpio_is_ready_dt(spec)) {
			return -ENODEV;
		}

		is_input = (pca9538.config & BIT(i)) != 0U;
		level = (pca9538.output & BIT(i)) != 0U;
		flags = is_input ? GPIO_INPUT : (level ? GPIO_OUTPUT_ACTIVE : GPIO_OUTPUT_INACTIVE);

		ret = gpio_pin_configure_dt(spec, flags);
		if (ret < 0) {
			return ret;
		}
	}

	return 0;
}

static uint8_t pca9538_input_value(void)
{
	uint8_t value = pca9538.output & ~PCA9538_HW_MASK;

	for (size_t i = 0; i < ARRAY_SIZE(mux_gpios); i++) {
		int ret = gpio_pin_get_dt(&mux_gpios[i]);

		if (ret > 0) {
			value |= BIT(i);
		} else {
			value &= ~BIT(i);
		}
	}

	return value ^ pca9538.polarity;
}

static uint8_t pca9538_read_reg(uint8_t reg)
{
	switch (reg & PCA9538_REG_MASK) {
	case PCA9538_REG_INPUT:
		return pca9538_input_value();
	case PCA9538_REG_OUTPUT:
		return pca9538.output;
	case PCA9538_REG_POLARITY:
		return pca9538.polarity;
	case PCA9538_REG_CONFIG:
		return pca9538.config;
	default:
		return 0xffU;
	}
}

static void pca9538_write_reg(uint8_t reg, uint8_t value)
{
	switch (reg & PCA9538_REG_MASK) {
	case PCA9538_REG_OUTPUT:
		pca9538.output = value;
		(void)pca9538_apply_outputs();
		break;
	case PCA9538_REG_POLARITY:
		pca9538.polarity = value;
		break;
	case PCA9538_REG_CONFIG:
		pca9538.config = value;
		(void)pca9538_apply_outputs();
		break;
	default:
		break;
	}
}

static int pca9538_write_requested(struct i2c_target_config *cfg)
{
	ARG_UNUSED(cfg);

	pca9538.reg_ptr_valid = false;
	return 0;
}

static int pca9538_write_received(struct i2c_target_config *cfg, uint8_t value)
{
	ARG_UNUSED(cfg);

	if (!pca9538.reg_ptr_valid) {
		pca9538.reg_ptr = value & PCA9538_REG_MASK;
		pca9538.reg_ptr_valid = true;
		return 0;
	}

	pca9538_write_reg(pca9538.reg_ptr, value);
	pca9538.reg_ptr = (pca9538.reg_ptr + 1U) & PCA9538_REG_MASK;
	return 0;
}

static int pca9538_read_requested(struct i2c_target_config *cfg, uint8_t *value)
{
	ARG_UNUSED(cfg);

	if (!pca9538.reg_ptr_valid) {
		pca9538.reg_ptr = PCA9538_REG_INPUT;
		pca9538.reg_ptr_valid = true;
	}

	*value = pca9538_read_reg(pca9538.reg_ptr);
	return 0;
}

static int pca9538_read_processed(struct i2c_target_config *cfg, uint8_t *value)
{
	ARG_UNUSED(cfg);

	pca9538.reg_ptr = (pca9538.reg_ptr + 1U) & PCA9538_REG_MASK;
	*value = pca9538_read_reg(pca9538.reg_ptr);
	return 0;
}

static int pca9538_stop(struct i2c_target_config *cfg)
{
	ARG_UNUSED(cfg);
	return 0;
}

static const struct i2c_target_callbacks pca9538_callbacks = {
	.write_requested = pca9538_write_requested,
	.write_received = pca9538_write_received,
	.read_requested = pca9538_read_requested,
	.read_processed = pca9538_read_processed,
	.stop = pca9538_stop,
};

static struct i2c_target_config pca9538_target_cfg = {
	.address = PCA9538_I2C_ADDR,
	.callbacks = &pca9538_callbacks,
};

int main(void)
{
	if (!device_is_ready(i2c_target)) {
		return 0;
	}

	if (pca9538_apply_outputs() < 0) {
		return 0;
	}

	if (i2c_target_register(i2c_target, &pca9538_target_cfg) < 0) {
		return 0;
	}

	k_sleep(K_FOREVER);
	return 0;
}

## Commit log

2024-08-15 Add blank project
    [dante-audio-board.kicad_pcb, dante-audio-board.kicad_sch]
2024-09-17 start block diagram
    [clock-generation.kicad_sch, dante-audio-board.kicad_sch, sbc-header.kicad_sch]
2024-09-20 start pcb
    [XTAC5112IRGER--3DModel-STEP-56544.STEP, dante-audio-board.kicad_pcb]
2024-12-06 add more CI steps
    [clock-generation.kicad_sch]
2024-12-06 continue to refine what goes into git
    [DAC53002RTER.step]
2024-12-06 add reference PDFs for board dimensions
2024-12-06 stab at HAT dimensions
    [dante-audio-board.kicad_pcb]
2024-12-06 fix basic 4 layer stackup
    [dante-audio-board.kicad_pcb]
2024-12-11 rename everything
    [clock-generation.kicad_sch, jkembedded-audio-board.kicad_pcb, jkembedded-audio-board.kicad_sch]
2024-12-11 fix DAC53002 path in clock-generation schematic
    [clock-generation.kicad_sch]
2024-12-11 fix path to BOM
2024-12-11 add placeholder for HAT adapter
    [mikroBus-HAT.kicad_sch]
2024-12-11 wip: not much to report yet
    [audio-codec.kicad_sch, jkembedded-audio-board.kicad_pcb]
2024-12-11 almost done with clocking, need series terminators
    [audio-codec.kicad_sch, audio-connectors.kicad_sch, clock-generation.kicad_sch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]
2024-12-11 mostly done with schematic of mikrobus board
    [audio-codec.kicad_sch, audio-connectors.kicad_sch, clock-generation.kicad_sch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]
2024-12-11 update some 3d models
    [jkembedded-audio-board.kicad_pcb]
2024-12-11 add view stage
    [jkembedded-audio-board.kicad_pcb]
2024-12-11 fix artifact name
    [jkembedded-audio-board.kicad_pcb]
2024-12-11 start on HAT by adding connectors
    [jkembedded-audio-board.kicad_pcb, mikroBus-HAT.kicad_sch]
2024-12-12 Move `WRD` to MCASP0_AFSX on BeagleY-AI
    See https://openbeagle.org/jkridner/jkembedded-audio-board/-/issues/1
2024-12-13 add 1-wire eeprom and a bit more
    [audio-codec.kicad_sch, audio-connectors.kicad_sch, clock-generation.kicad_sch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]
2024-12-13 Add audio jack footprint with reference to right 3D model
2024-12-13 add MSMP0
    [mikroBus-HAT.kicad_sch]
2024-12-13 add MSPM0
    [clock-generation.kicad_sch, jkembedded-audio-board.kicad_pcb]
2024-12-30 add clickid
    [clock-generation.kicad_sch, mikrobus-header.kicad_sch]
2024-12-30 added some muxes, about to add 3-way mux
    [jkembedded-audio-board.kicad_pcb, mikroBus-HAT.kicad_sch]
2024-12-30 stopping for the day
    [jkembedded-audio-board.kicad_pcb, mikroBus-HAT.kicad_sch]
2025-02-18 Resolve #5: Finished up ClickId Ciruit
    [audio-codec.kicad_sch, clock-generation.kicad_sch, mikroBus-HAT.kicad_sch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]
2025-02-19 add extra labels to MB and title. specify project in CI file and update to Kicad 8.0.8
    [audio-codec.kicad_sch, clock-generation.kicad_sch, jkembedded-audio-board.kicad_sch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]
2025-02-19 Resolved #4: Removed Unnecessary connectors for first revision
    [mikroBus-HAT.kicad_sch]
2025-02-19 Resolved #2: Matched 4 clock outputs to expected by DEP
    [clock-generation.kicad_sch, jkembedded-audio-board.kicad_sch, mikrobus-header.kicad_sch]
2025-02-20 Resolved #1: Mapped switches to HAT with uP Control (2nd attempt... missed committing file previously)
    [mikroBus-HAT.kicad_sch]
2025-02-20 remove unused INT
    [jkembedded-audio-board.kicad_sch, mikroBus-HAT.kicad_sch]
2025-02-20 added ability to program MCU
    [jkembedded-audio-board.kicad_sch, mikroBus-HAT.kicad_sch]
2025-02-20 improve front page
    [jkembedded-audio-board.kicad_sch]
2025-02-20 Add TS
    [jkembedded-audio-board.kicad_sch, mikrobus-header.kicad_sch]
2025-02-20 worked through ERCs and updated PCB components
    [audio-codec.kicad_sch, clock-generation.kicad_sch, jkembedded-audio-board.kicad_pcb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]
2025-02-24 Resolved #6: Added connection options for IN_COMMON and OUT_COMMON for audio codec
    [audio-codec.kicad_sch]
2025-02-26 Resolved #7: swapped click board header connections and finished first pass routing
    [clock-generation.kicad_sch, jkembedded-audio-board.kicad_pcb, mikroBus-HAT.kicad_sch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]
2025-02-28 Resolved #8: connected RST_WRD_B to HAT pin 7 through 0 ohm resistor
    [jkembedded-audio-board.kicad_pcb, jkembedded-audio-board.kicad_sch, mikroBus-HAT.kicad_sch]
2025-02-28 Resolved #9: removed mikroBUS connector alignment holes
    [jkembedded-audio-board.kicad_pcb]
2025-02-28 minor DRC tweaks
    [clock-generation.kicad_sch, jkembedded-audio-board.kicad_pcb]
2025-02-28 more PDFs of pcb
2025-04-10 fill inner layers with copper
    [jkembedded-audio-board.kicad_pcb]
2025-04-10 Add version to silkscreen
    [jkembedded-audio-board.kicad_pcb]
2025-04-10 Add feedback from CircuitHub
    [64925-CH0015be53-BOT-MIRRORED.tsv, 64925-CH0015be53-BOT.tsv, 64925-CH0015be53-TH-TOP.tsv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]
2025-04-11 Increase space between boards and add mounting holes
    Closes https://openbeagle.org/jkembedded/jkembedded-audio-board/-/issues/11
    [jkembedded-audio-board.kicad_pcb]
2025-04-11 CI: put DRC in log and make zip for CircuitHub
2025-04-11 Back-annotate BOM from CircuitHub
    [audio-codec.kicad_sch, clock-generation.kicad_sch, mikroBus-HAT.kicad_sch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]
2025-04-29 initial power notes
2025-04-30 bringup: i2c working
2025-10-15 remove TS
    [audio-codec.kicad_sch, clock-generation.kicad_sch, jkembedded-audio-board.kicad_sch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]
2025-10-15 update pcb to kicad 9
    [jkembedded-audio-board.kicad_pcb]
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2025-12-30 Aligned connector with hole
    [jkembedded-audio-board.kicad_pcb]
2025-12-30 Added leds on Power and Mux sel lines per issues 12 and 15
    [clock-generation.kicad_sch, mikroBus-HAT.kicad_sch]
2025-12-30 added series caps per issue 17
    [audio-codec.kicad_sch, jkembedded-audio-board.kicad_sch, mikrobus-header.kicad_sch]
2025-12-30 Added zero ohm resistors to XTAC5112 inputs
    [audio-codec.kicad_sch]
2025-12-30 Added SWD debug header per issue 22
    [mikroBus-HAT.kicad_sch]
2025-12-30 debug header added to bom, patts synced to pcb... still need to route
    [jkembedded-audio-board.kicad_pcb, mikroBus-HAT.kicad_sch]
2025-12-31 In process routing edits
    [audio-codec.kicad_sch, jkembedded-audio-board.kicad_pcb]
2026-01-04 Working through DRCs
    [jkembedded-audio-board.kicad_pcb, mikrobus-header.kicad_sch]
2026-01-08 Changed codec rail to 3V3_Osc and addressed all DRCs (including previous overrides)
    [audio-codec.kicad_sch, clock-generation.kicad_sch, jkembedded-audio-board.kicad_pcb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]
2026-01-08 Add MSPM0 Zephyr board configuration and pin map (#3)
    * Add Zephyr board config for MSPM0 mux controller
    * Update MSPM0 board naming and PCA9538 emulation docs
    * Add Zephyr build smoke test for MSPM0 mux firmware
    * Pin Zephyr CI build container version
    * Fix MSPM0 board Kconfig dependency
    * Add Zephyr formatting config and CI checks
    * Add west manifest and init steps for MSPM0 Zephyr build
    * Simplify west init path and update docs
    * Use shared west build script in GitHub CI
    * Ensure ZEPHYR_BASE is set before DTS lint
    * Run lint and format inside shared Zephyr build script
    * Remove unused west commands placeholder
    * Skip west init when workspace already exists
    * Add tracing and s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
    [main.c]
2026-01-13 Added revision notes to schematic, added ci debug output
    [jkembedded-audio-board.kicad_sch]
2026-01-13 debugging ci error: jobs:print:script config should be a string or a nested array of strings up to 10 levels deep
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2026-01-13 Updated template variables and pcb date/version
    [audio-codec.kicad_sch, clock-generation.kicad_sch, jkembedded-audio-board.kicad_pcb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]
2026-04-09 Add details about board connections for host-programmer
2026-04-12 update Debian image and test on correct board
2026-04-12 mspm0: document and build fixed mux image
    [main.c]
2026-04-13 mspm0: switch bring-up app to i2c target
2026-04-13 mspm0: checkpoint direct i2c target debug app
2026-04-14 mspm0: switch pa19 pa20 scope test to zephyr gpio
2026-04-22 mspm0: invert an int selector test state
    [main.c]
2026-04-23 mspm0: add minimal i2c eeprom target app
2026-04-23 docs: record mspm0 i2c target validation
2026-04-23 firmware: share mikrobus_hat board definition
2026-04-23 ci: fix local clang-format failures
    [main.c]
2026-04-23 docs: simplify gpio switch configuration
2026-04-23 docs: validate rst via hat pin 7
2026-06-11 Add HAT MCU_RESET/BOOTLOADER_SEL GPIO inputs to host overlays (#10)
    ### Motivation
    Expose the HAT pins used for MCU reset and bootloader selection as stable host-visible GPIO line names so host tooling can drive reset and enter BSL consistently across supported boards.
    ### Description
    - Added host overlay fragments for the HAT MCU control pins:
    - `GPIO24` → `MCU_RESET`
    - `GPIO25` → `MCU_BOOTLOADER_SEL`
    - Updated supported host overlays under `firmware/host-integration/linux/*/mspm0-pca9538-gpio.dts`.
    - Configured the new lines as GPIO input hogs with stable `line-name` values.
    ### Board mappings
    - BeagleY-AI:
    - `GPIO24`: `&mcu_gpio0`, `gpios = <10 0>`
    - `GPIO25`: `&main_gpio0`,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
